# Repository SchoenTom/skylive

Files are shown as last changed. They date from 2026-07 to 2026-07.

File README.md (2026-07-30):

<div align="center">

# SkyLive

### A skydiver exits at 4 000 m. Before the canopy opens, the drop zone is already watching through her eyes.

**Live from 4 km — 14 ms behind reality.**

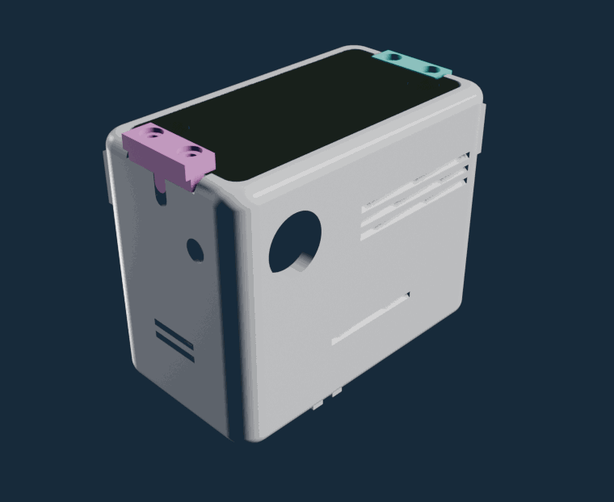
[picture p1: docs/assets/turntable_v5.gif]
The Sender 850 turning slowly: battery door with tab latch, T-clamp antenna anchors on both short sides, roof lid, louvres, GoPro mount.
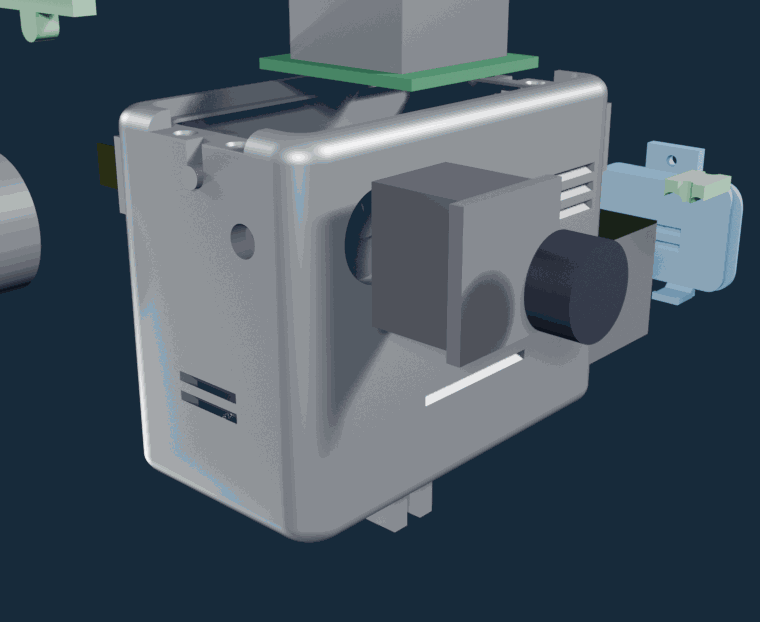
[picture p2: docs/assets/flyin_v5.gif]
Every component — radio, camera, battery, antenna, clamp bars, T-pieces — flying into the open case.
 

<sub>the actual gate-verified CAD — spin it and watch the parts fly home yourself in the [3D Lab](https://schoentom.github.io/skylive/viewer.html)</sub>






**[▶ Play the jump](https://schoentom.github.io/skylive/)** · **[🧊 3D Lab](https://schoentom.github.io/skylive/viewer.html)** · **[🪂 Freefall Simulator](https://schoentom.github.io/skylive/freefall.html)** · **[🚧 Gate Simulator](https://schoentom.github.io/skylive/gates.html)** · **[⚖ vs GoPro](https://schoentom.github.io/skylive/viewer.html)** · **[🎛 Antenna decks](https://schoentom.github.io/skylive/decks/)** · **[Build it — one page](build/QUICKSTART.md)** · **[What the gates caught](build/WHAT_THE_GATES_CAUGHT.md)** · **[The numbers](build/rf/README.md)** · **[Legal (DE)](build/LEGAL_DE.md)**

</div>

---

## What if the whole drop zone could watch — live?

<div align="center">
Left: what the ground sees today — just a dot in the sky. Right: what SkyLive shows — the freefall POV live on a monitor, same moment, ~14 ms.
</div>

Today the ground sees **a dot in the sky**. Spectators, the waiting area, your own team — they follow the jump with the naked eye, and the footage arrives only *after* landing. The moment itself stays invisible.

**SkyLive** puts the jump on the screen **as it happens**. A helmet-mounted transmitter the size of an action cam sends a digital HDZero picture from ~4 km up, down its own 5.8 GHz radio link — no internet, ~14 ms — straight onto the big TV in the waiting area. Not a recording. **The present tense.**

<div align="center">
The signal's journey: camera → 1 W radio → antenna → ~4 km of air → ground antennas → receiver → HDMI → the big TV in the waiting area, in about 14 ms.
</div>

---

## Four parts. Two ways to wire them.

That's the entire transmitter: **a radio, a camera, a battery, and a button.** The simplicity *is* the design — and you pick your wiring path:

- **Soldered (recommended for the flight unit):** every lead cut to its true run length — shorter cables, less weight, nothing to rattle, the most robust joints a jump can ask for.
- **Wago quick-build (great first build):** three 221-412 lever clamps, zero solder, re-openable in seconds — perfect while you're still iterating.

| | part | what it does | the real part |
|---|---|---|---|
| 📡 | **Radio (VTX)** | turns the picture into a 1 W digital signal, ~14 ms | HDZero Freestyle V2 (30 × 29 × 14 mm, runs directly on 3S — no flight controller, no BEC) |
| 👁 | **Camera** | HD skydive POV, 162° | HDZero Nano90 (ships in the VTX kit, powered over its MIPI cable) |
| 🔋 | **Battery** | ~40 min at 1 W (calculated: 850 mAh / ~1.3 A) | Tattu R-Line 3S 850 mAh (XT30) |
| 🔘 | **Switch** | on/off — breaks the battery + line directly | 12 mm latching push-button, panel-mount |

The VTX side plugs in via its stock **JST-GH 6-pin harness** either way. Full step-by-step (with the three hardware-killer rules): **[`build/BUILD_GUIDE.md`](build/BUILD_GUIDE.md)**.

**The shell:** an upright, two-storey GoPro-style case — battery downstairs behind its own tab-locked door, radio + camera upstairs under a screwed roof lid — printed in **PETG/ASA (never PLA)** with a sacrosanct **3 mm wall**, long passive louver vents, and a GoPro mount underneath. Outer dimensions: **71 × 40 × 56 mm** — genuinely action-cam-sized. Both short sides carry an identical **T-clamp strain-relief interface** at the top edge — guide slot, round seat, and a screw-driven nose clamp — so the antenna can anchor left or right; the unused side is closed by the same T-piece. It builds from the parametric script in [`build/cad/`](build/cad/) and passes every geometry gate on each rebuild; this exact file set is what went to the printer.

**Three sizes, one architecture.** Don't take a photo's word for it — **[spin them in the 3D Lab](https://schoentom.github.io/skylive/viewer.html)**, where every dimension tag is a real millimetre from the executed CAD. The **850** (71 × 40 × 56 mm) is the flight unit; the
**mid sender** (72 × 39 × 57 mm) and the **Mini 300** (59.5 × 39.5 × 48 mm) are the same design
wrapped around the smaller Tattu 300 3S HV pack (measured 45 × 17.5 × 15.3 mm) —
same T-clamp antenna anchors (literally the same printed T-piece), same tab door, same camera corner.

---

## One antenna, anchored like a tool — not like an afterthought.

There is **no electronic antenna switch** on the sender — the omni rides outside on its
semi-rigid coax, and the clever part lives where it belongs: on the ground.

The mount is a proper screw clamp, measured off a working reference build's STEP files: the
**Ø 3.1 mm** semi-rigid coax drops from above through a guide slot **all the way down** into a
round Ø 3.2 seat that passes horizontally through the case wall — the seat has clearance, on
purpose. The clamping is the **T-piece's job**: its stem ends in a **convex nose of R 1.55 mm —
exactly the cable's radius** — and two vertical M2 cap screws pull that nose 0.4 mm down onto
the cable, pinching it into the seat. The screws *are* the clamp; a yank on the antenna loads
the printed wall and the bolted nose, never the connector. Outside, the **RHCP omni sits
directly against the wall, its axis horizontal, pointing straight through it**. That 90° turn
is the whole point: an upright omni's donut pattern has its nulls pointing up and down, which
in head-up *and* head-down would aim a null exactly at the receiver. Lying sideways, the donut
fires **down and up and all around** — signal toward the ground in every jump attitude. Both
short sides carry the identical interface, so the anchor moves left or right to suit the helmet
setup — one T-piece design, printed twice, no drilling, no notching.

| honest caveat | status |
|---|---|
| Body shadow, not the antenna, is the limiter in belly/sit poses (−7…−12 dB literature midpoints) | assumption, to be jumped |
| Nose clamp holding force and S11 with the coax clamped | `MEASURE_ME` — fit-print pull test + NanoVNA |
| CAD asserts a 0.4 mm nose-to-cable engagement (1.15 mm³) on every rebuild | calc, not a torque test |

Two earlier antenna integrations — the fully **encapsulated side-capsule omni** and the
**down-firing patch shell** — are preserved as engineering studies with their full RF derivations
in [`build/ENGINEERING/antenna_capsule.md`](build/ENGINEERING/antenna_capsule.md); the external
anchored omni won on serviceability (swap an antenna in seconds, nothing to detune, one part to
reprint).

**The gain lives on the ground.** You're tumbling; the ground isn't. A bigger helmet antenna buys ~2–3 dB; the ground antenna buys 10+ dB. But not by tracking — a mover has a zenith keyhole exactly where the jump happens. The doctrine is **several fixed beams**: one at the zenith, three around the horizon, and the receiver's 4-way diversity fuses the branches. The beams themselves are **self-printed axial-mode helix antennas** (5.8 GHz, RHCP, 7 turns, C/λ 1.00, 10.5° pitch, copper-tape cup reflector — the higher-gain cone *loses* in the minimax over real geometry despite +4 dB peak; HPBW ~37°). Gain, honestly: estimators span **10.7–13.9 dBic — measurement decides.** Each helix sits on a ball head so elevation is set in the field, the receiver's stock 2 dBi stubs come off (HDZero fuses by data integrity — one bad branch degrades the whole picture), and a Wi-Fi scan of the drop zone happens before anything transmits (5.8 GHz video channels overlap Wi-Fi). The store-bought patch-plus-omnis set remains as the interim/comparison station.

---

## The numbers — calculated, labelled, and published even when they got worse

<div align="center">
Link budget at 4 km: +30 dBm transmit, −119.8 dB free-space loss, honest RX gain, −90 dBm threshold — head-down closes with margin, belly rides the threshold; a model, not a measurement.
</div>

| | value | status |
|---|---|---|
| 📡 Transmit power | +30 dBm (1 W) — 25 mW SRD for all tests, PMSE assignment for the event | planned path |
| 📡 Free-space loss @ 4 km | 119.8 dB (5.8 GHz, Friis) | derived |
| 📡 Link margin @ 4 km | **head-down ≈ +9 dB** · back ≈ +3 dB · **belly rides the threshold** (−0.2 dB) · sit ≈ −2 dB — margins improve 2–3 dB per km of descent | **calculated, not measured** |
| 🧍 Body shadow | −7…−12 dB with the side-mount offset (literature midpoints) — the single biggest uncertainty | assumption, to be jumped |
| 🌡 Heat at 1 W | **~13 W of waste heat.** On the ground, in still air, no passive case can hold that — so the doctrine is 25 mW on the ground, **1 W only at door-open**; in freefall the 200 km/h wind is the heatsink (4–8× surplus) | calculated |
| ⏱ Latency | ~14 ms | manufacturer figure |

The full model — pattern math, pose-by-pose margin tables, every assumption and its direction of error — is in [`build/rf/`](build/rf/), including an **interactive link-budget explorer** you can open in any browser. The thermal, structural and print derivations live in [`build/ENGINEERING/`](build/ENGINEERING/).

> **No overclaiming.** A CAD boolean check is not a test. Nothing in this repo carries a *measured* badge yet — and when the 2026 recalculations made numbers worse, the worse numbers were published.

---

## Build one yourself

Everything a re-builder needs is under [`build/`](build/):

- 📋 **[`BUILD_GUIDE.md`](build/BUILD_GUIDE.md)** — both wiring paths (soldered flight build, Wago quick-build), the wiring map, the three hardware-killer rules, and the power/thermal operating doctrine.
- 🛒 **[`BOM.md`](build/BOM.md)** — every part with real EU prices (as of 2026-07).
- 📐 **[`MEASURE.md`](build/MEASURE.md)** — the dimensions you must caliper yourself (nothing in this project is guessed).
- ✅ **[`VERIFICATION.md`](build/VERIFICATION.md)** — how a CAD model is turned into a *trustworthy* printable part: a seven-layer defense-in-depth, the honest limits of gates vs. physical tests, and the release checklist.
- ⚖️ **[`LEGAL_DE.md`](build/LEGAL_DE.md)** — the German regulatory situation, honestly: what is legal today (25 mW SRD), what the event path is (PMSE), and why 1 W under an amateur licence is locked pending clarification.
- 🧊 **[`cad/`](build/cad/)** — the parametric build123d scripts (`spec.py` is the single source of truth for every dimension).

<div align="center">
Latency: ~14 ms — before you blink. The old way is footage seen only after landing.
</div>

---

## Status

**Print released** (2026-07). The concept, the electronics, the RF doctrine and the engineering derivations are done and published here; the case design is frozen, and the first fit-prints are back from the printer: the printed GoPro fork clicks into a real GoPro mount and the parts fit as drawn (builder fit test, 2026-07-15).

- ✅ Sender electronics bought and specified — four parts, two wiring paths (soldered flight build, Wago quick-build).
- ✅ RF doctrine derived and published (donut orientation, multi-beam ground station, legacy capsule study) — *calculated*.
- ✅ Thermal, structural and print-factor derivations published — *calculated*.
- ✅ Final case CAD (**71 × 40 × 56 mm**) builds watertight and passes every geometry gate — roof lid on 2 diagonal M3 corner inserts (was 3 — round-2 port), tab-locked battery door, twin T-slot antenna anchors, 3 mm wall. **Print files released — and the first fit-prints are back: the GoPro interface locks into a real mount, the parts fit.** *Fit-verified by print (2026-07-15); strength and RF stay open below — a fit is a geometry result, not a pull test.*
- ✅ **Mid sender** (72 × 39 × 57 mm) and **Mini 300** (59.5 × 39.5 × 48 mm, Tattu 300 3S HV): full architecture ports of the final build — same T-slot anchors (the T-pieces are literally the same printed part), same tab door; the Mini has no power switch (the electronics storey has no room for one; power = plug the battery). [`build/cad/mid_sender.py`](build/cad/mid_sender.py) · [`build/cad/mini_300.py`](build/cad/mini_300.py), *geometry-verified, not yet printed.*
- ✅ **Engineer feedback round 2 (2026-07-25), mid sender:** printed prototypes went through a professional mechanical review — everything that broke, broke at a layer seam while removing support. Fixes, each proven by a point-cloud diff against its target zone ([`build/cad/mesh_diff.py`](build/cad/mesh_diff.py)): mid back to **71 mm** (a 2 mm squeeze had eaten the power-switch bay — the switch check is a hard, whole-body gate now), camera flange rooted on the mid-storey shelf, XT30 strain relief rebuilt as a wall-to-wall clamp bridge with a solid latch bar, door teeth straight with 45° fan roots into the plate, omni side-holders removed, roof lid down to 2 diagonal M3. **One-material doctrine:** colour metadata in the STEP exports had been flipping lab printers into multi-material mode (seven aborted prints) — all exports are colour-free now; slice the STLs only. *Geometry-verified (mesh diffs, hard gates, 6/6 printability); the round-2 fit-print is still open.* Sub-mm audit: [`build/cad/SUBMM_INVENTUR_2026-07-25.md`](build/cad/SUBMM_INVENTUR_2026-07-25.md).
- ✅ **Unified port (2026-07-26): all three senders now follow the same principles.** Camera foot, wall-to-wall XT30 clamp bridge + flat latch v3, straight door teeth with a full-width root bar, omni side-holders removed — ported to the 850 and Mini 300 with each model's own gates re-proving the result (the Mini rejected the diagonal-lid port outright: its corner boss would sit inside the VTX envelope, 320 mm³ — its two edge screws stay). Lid rim audited on all three (≥1.4 mm standing lip; the mid's Y-lap dropped to 1.25 to get there), and every door louver now has to prove 19/19 free 45-degree air paths at export — perviousness is invisible in renders, so it became a gate.
- 🔜 Then: thermal measurement (multimeter protocol is written) → antenna S11 with the coax clamped → clamp pull test → 25 mW range test → test jump.

### Modelled → gated → printed — the provenance trail

Everything physical in this project traces end to end; nothing here is a mockup:

- **Modelled.** Three senders — 850, mid, Mini 300 — each generated by one executed build123d
  script ([`v3_min.py`](build/cad/v3_min.py) · [`mid_sender.py`](build/cad/mid_sender.py) ·
  [`mini_300.py`](build/cad/mini_300.py)), six printed parts per size: the one-piece two-storey
  **body**, the tab-locked **battery door** (M2 brass insert), the **roof lid** (3× M3 corner
  inserts), **2× XT30 clamp bar** and **2× strain-relief T-piece** (proud + flush). The GoPro
  two-prong fork is printed into the floor of the body — teeth 3.0, gap 3.3, drawn against
  caliper-measured hardware. All 18 release STLs live in [`build/stl/`](build/stl/).
- **Gated.** Every STL passed the release chain before it was allowed to exist: watertight
  boolean, the nominal-envelope interior gates (the same arithmetic the
  [Gate Simulator](https://schoentom.github.io/skylive/gates.html) replays), and
  [printability gate v2](build/cad/printability_gate.py) — thin-wall plateau = FAIL, cosmetic
  cusp = WARN. What the gates caught on the way is documented in
  [`WHAT_THE_GATES_CAUGHT.md`](build/WHAT_THE_GATES_CAUGHT.md); the layer-by-layer method in
  [`VERIFICATION.md`](build/VERIFICATION.md).
- **Printed.** The first fit-prints are back (PETG, per [`PRINT_DE.md`](build/PRINT_DE.md)):
  **the printed GoPro fork clicks into a real GoPro mount, and the printed parts fit as
  drawn** — builder fit test, 2026-07-15. That upgrades the GoPro row in the ledger below from
  *printing* to *fit-verified*. Still open and honestly labelled: thermal, S11 and the pull
  test — a part that fits is a geometry result, not a strength or RF result.

⭐ **Star the repo** — releases will carry the first real measurements and, eventually, the first freefall footage from the system itself. Building one, or flying camera and have opinions? Open an [issue](https://github.com/SchoenTom/skylive/issues).

---

## The jump, as a number line

```
4000 m ─┤ ██ EXIT      link margin: head-down +9 dB · belly −0.2 dB   [CALC]
3000 m ─┤ ██ freefall  ~200 km/h — the airstream IS the heatsink      [CALC]
1500 m ─┤ ██ canopy    margins improve 2–3 dB per km of descent       [CALC]
 300 m ─┤ ██ pattern   fixed ground beams — the receiver fuses 4 branches
   0 m ─┴─▓▓─ beer     footage was live the whole way down            [PLAN]
```

<sub>margins = the conservative single-beam floor from [`build/rf`](build/rf); the BoxPro's
four fused helix branches ride 10–15 dB higher — [fly it yourself in the simulator](https://schoentom.github.io/skylive/freefall.html).</sub>

## Truth ledger — what is measured, what is math

The whole repo runs on a two-word doctrine: **a CAD boolean is not a test.** Current state of
every load-bearing number:

| number | value | status |
|---|---|---|
| case dimensions, all three senders | 71×40×56 · 72×39×57 · 59.5×39.5×48 | 🟢 executed CAD, gate-checked |
| battery | 58×30×22 (850) · 45×17.5×15.3 nominal — the real wrapped pack binds at 18.25 light width, guides opened to 18.75/16.55 (mid + Mini | 🟢 measured with calipers |
| brass inserts | M3 Ø5×6 · M2 Ø3.2×3 | 🟢 measured |
| XT30 wire, coax jacket | Ø2.8 · Ø3.1 | 🟢 measured |
| GoPro teeth 3.0 / gap 3.3 | printed — clicks into a real GoPro mount, fits as drawn | 🟢 fit-verified by print (2026-07-15) |
| antenna clamp holding force | screw-driven nose, 0.4 mm engagement (calc) | 🔴 MEASURE_ME — pull test pending |
| antenna S11, insert strength, snap cycles | — | 🔴 MEASURE_ME |
| link budget @ 4 km, thermal model | full derivations in build/rf | 🟡 CALC — to be jumped |

🟢 measured · 🟡 calculated/derived and labelled · 🔴 open, honestly. When the 2026 recalculations
made numbers worse, the worse numbers were published — that policy stands.

## Honest note

A solo-built, prototype-stage project shared in full. Calculated values are marked as such and separated from what still has to be measured. Transmit power is regulated: the plan of record is licence-free **25 mW SRD** for all development tests and a **PMSE short-term frequency assignment** for event operation — see [`DISCLAIMER.md`](DISCLAIMER.md) and [`build/LEGAL_DE.md`](build/LEGAL_DE.md).

<sub>License: <a href="LICENSE">CC-BY-4.0</a> · CAD: build123d (Python) · Made by <a href="https://github.com/SchoenTom">@SchoenTom</a></sub>

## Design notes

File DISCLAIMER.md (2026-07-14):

# ⚠️ Disclaimer — RF, safety, status

**SkyLive** · Copyright (c) 2026 Tom Schoen ([@SchoenTom](https://github.com/SchoenTom)) · Licensed [CC BY 4.0](LICENSE)

## Radio / regulatory

Radio transmit power is regulated. The plan of record for this project is **licence-free SRD at 25 mW EIRP** for all development and testing and a **PMSE short-term frequency assignment** (BNetzA, Germany) for event operation. Operating at 1 W under an amateur-radio licence is a legal grey zone in Germany (§5 AFuG / §16 AFuV, plus a hard bandwidth cap) — it is *not* what this project relies on; the full reasoning is in [`build/LEGAL_DE.md`](build/LEGAL_DE.md). **Anyone reproducing this work is responsible for their own regulatory compliance in their own jurisdiction.**

## Safety

This device is designed to be worn on a skydiver's helmet next to life-critical equipment. The documentation includes the safety concept (snag-free shell, screw-clamped captive antenna, tab-locked battery door, strain relief, thermal operating doctrine, SAR assessment and AAD manufacturer sign-off as hard gates before any jump) — **none of it is validated yet**. Do not jump any build of this hardware before the documented ground gates pass, a written AAD manufacturer statement exists, and the drop zone / safety officer has approved it.

## Status

Prototype-stage engineering, shared in full. Calculated values are marked as calculated; nothing carries a "measured" badge yet. The material is provided **"as is", without warranty of any kind**. This is not a validated, certified, or sellable product.

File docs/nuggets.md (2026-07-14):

# SkyLive — five numbers that carry the design

*Five engineering "nuggets" — one number each, a few sentences each. The kind of small, exact
figure that a whole design quietly hangs on. Sourced where sourced, **[CALC]** where modelled,
honest either way. Card texts for the show layer; the derivations live in [`../build/`](../build/).
These five render as number cards in the Pages site (docs/index.html).*

---

### R 1.55
**The nose that matches the cable exactly.**
The antenna cable drops all the way down into a round seat with clearance — insertion never fights
the print. Then the T-piece's stem lands on it: a convex nose of radius 1.55 mm, precisely the
cable's own radius, so it cradles instead of cutting. Two vertical M2 screws pull that nose 0.4 mm
onto the cable — the screws are the clamp, measured 1:1 off a working reference build. A yank on
the antenna loads the printed wall and the bolted nose, never the connector.

---

### −0.2 mm
**The squeeze standard (where squeezing is right).**
The battery-lead saddles are under-sized by a tiny, deliberate amount: 0.2 mm less than the wire
they hold. It's the line between gripping and crushing. The antenna clamp deliberately does NOT use
it — coax hates being squeezed by tolerances (it detunes), so there the seat has clearance and two
screws deliver a controlled, serviceable clamping force instead. Same goal, two honest mechanisms.

---

### 90°
**The turn that dodges the null.**
The omni doesn't stand upright like on an FPV quad — its coax runs horizontally through the case
wall and the bell sits directly against it, axis pointing straight through the wall. An upright
omni's donut pattern has nulls straight up and down: in head-up or head-down freefall that aims a
blind spot exactly at the receiver. Laid sideways, the donut fires down, up and all around — signal
toward the ground in every jump attitude. And the strain relief becomes trivially simple: the cable
never turns, so the T-clamp just drops onto it and screws shut.

---

### 14 ms
**Glass-to-glass latency.**
From the lens in freefall to the picture on the ground TV is about 14 milliseconds — faster than a
blink, faster than you can perceive as delay (manufacturer figure). It's not the internet and it's
not a stream; it's a private digital radio link with nothing in the middle to buffer. The jump you
watch on the screen *is* the jump happening in the sky, in the present tense.

---

### 4 parts
**No flight controller. No BEC. One printed body.**
The entire transmitter is four things — a radio, a camera, a battery, and an antenna — inside one
printed body. Every FPV builder expects a flight controller, a voltage regulator, a rat's nest of
wiring; there is none of it here. The few joints that remain are soldered once, properly, for
flight — every joint earns its place. The restraint *is* the engineering: fewer parts, fewer
failure points.

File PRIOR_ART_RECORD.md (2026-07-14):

# SkyLive — Prior-Art / Authorship Record ("Sicherheit B")

**Purpose:** dated internal record of authorship of the SkyLive concept — an
open, helmet-mounted 5.8 GHz live-video *sender* + open ground-station system for
broadcasting a skydiver's own point of view to the drop zone in real time — kept
as a backup in case the idea is copied.

**Recorded:** 2026-07-08
**Author / owner:** GitHub `SchoenTom` (this is the account of record for SkyLive).

---

## ⚠️ The primary proof is NOT this file

A local file's timestamp can be altered, so it is weak on its own. The
authoritative, hard-to-repudiate evidence of first public disclosure is:

- **"Sicherheit A" — the public repo `skylive` on GitHub** (`SchoenTom/skylive`),
  with **server-side git commit timestamps** and the **CC-BY-4.0 license**
  (which legally requires attribution to the author on any reuse). That is
  timestamped public prior art. This file is a supplementary backup only.

To harden the anchor further (optional, recommended):
- Commit *this* record into the public repo so it, too, gets a server timestamp.
- Cut a dated, tagged release of the concept docs.
- Add an external timestamp (e.g. OpenTimestamps) to a hash of the key files.

---

## Context of this record

On 2026-07-08 the author applied to Anthropic's open-source / Claude Max program,
presenting SkyLive as the flagship project. This file preserves the submitted
description of the concept as of that date.

## The concept, as disclosed

An **open-source, reproducible** system — buildable by anyone — that live-streams
a skydiver's own point of view to the drop zone as the jump happens
(~14 ms latency, ~4 km range, 5.8 GHz HDZero). Novelty vs. prior state: this
capability existed only in **closed, commercial** broadcast rigs; SkyLive
publishes the **whole chain — helmet sender to open Linux ground station** —
under CC-BY-4.0 so anyone can rebuild it. Deliberate full disclosure (the
patentable ideas were released rather than locked up).

*(2026-07-14 note: the ground-station concept has since evolved into a multi-beam
station with self-printed helix antennas.)*

## Submitted application answers (verbatim, as of 2026-07-08)

**Q1 — reach & impact / gap in the ecosystem:**
> My mission is to make everything I build open and freely reproducible, so
> anyone can use it — not only hardware, but quantitative-finance research that is
> normally locked behind institutions and paywalls. I publish my results and tools
> openly so students, independent researchers, and everyday people can benefit from
> methods usually reserved for a few. My flagship project, SkyLive, carries that
> same spirit into a field that has no open answer yet: it takes a capability that
> today exists only in closed, commercial form and turns it into a fully open
> design anyone can rebuild.

**Q2:**
> The impact I aim for is access: taking things that are normally closed,
> expensive, or locked behind institutions — from finance methods to hardware —
> and making them open, reproducible, and free for anyone to use, verify, and
> adapt. My work is meant to belong to the people who use it rather than to a
> vendor's customers. SkyLive is one example of that, opening a capability a whole
> community could never afford before.

**Q3:**
> Everything I build is developed in the open, across finance and hardware, and I
> publish the results and tools so others can use and verify them — not just read
> about them. It's an early but growing body of work, reproducible from day one,
> aimed at steadily widening who gets access. SkyLive is the flagship carrying
> that forward.

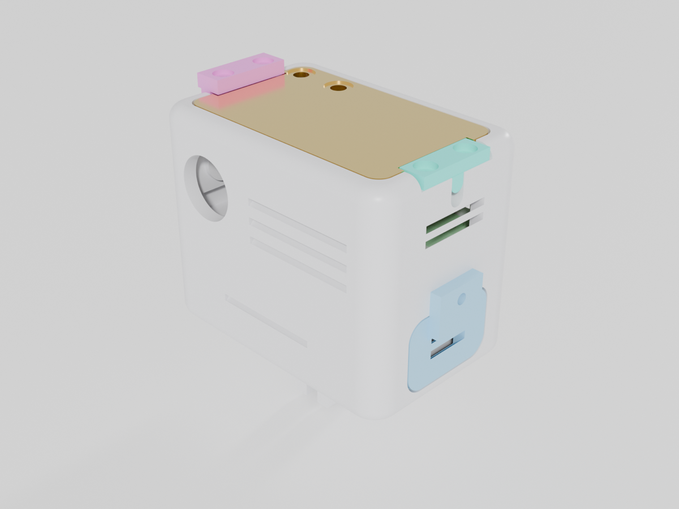
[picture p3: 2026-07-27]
docs/poster_mini_v1.png

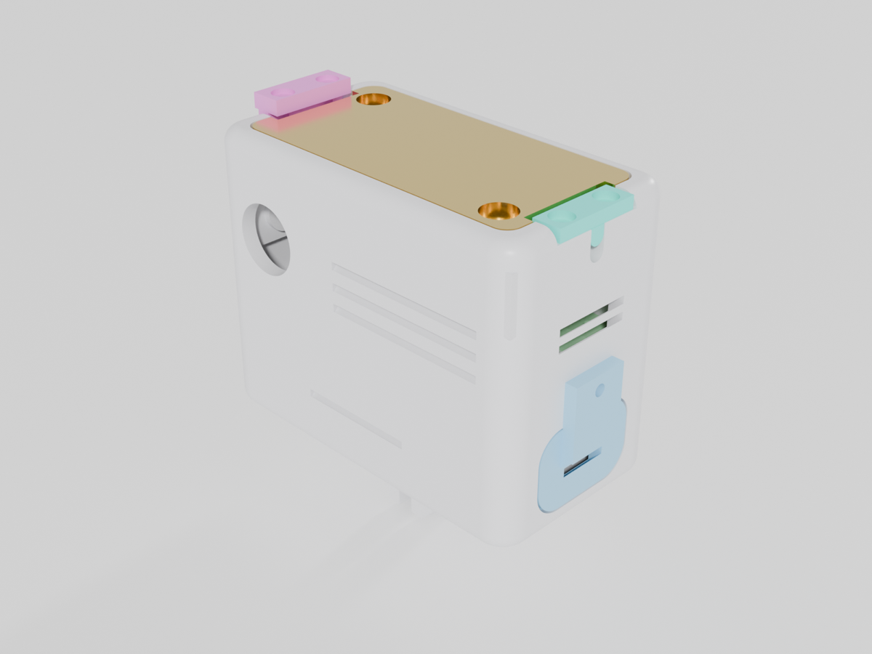
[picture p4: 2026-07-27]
docs/poster_mid_v1.png

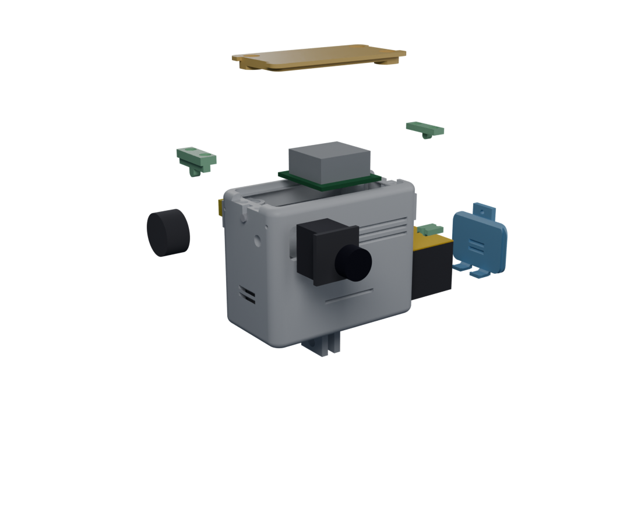
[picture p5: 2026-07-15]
docs/poster_exploded_v4.png

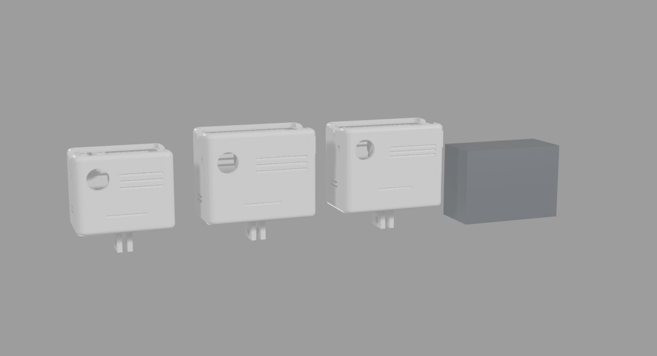
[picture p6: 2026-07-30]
docs/poster_cmp_v2.png

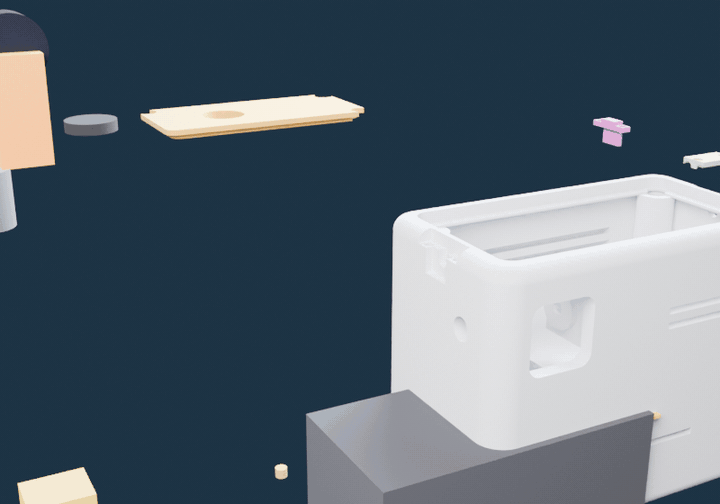
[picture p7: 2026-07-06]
docs/assets/flyin.gif

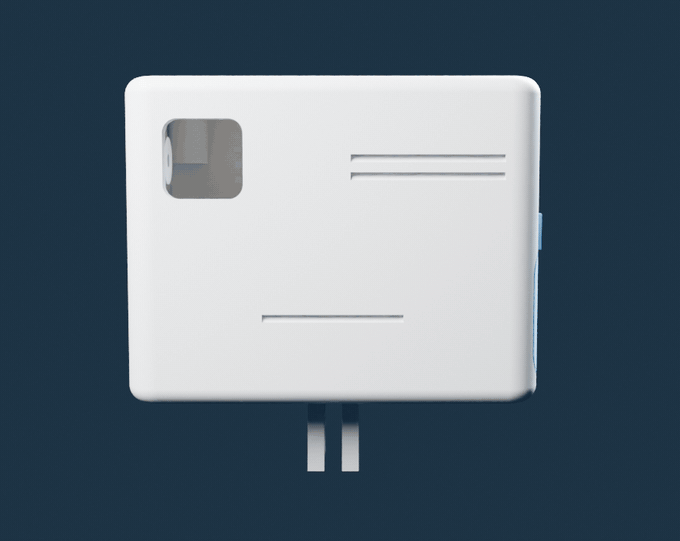
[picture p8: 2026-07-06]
docs/assets/turntable.gif

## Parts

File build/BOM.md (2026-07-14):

# SkyLive — Bill of Materials

*Prices as of 2026-07, EU/DE vendors, from the project's real order log (German original:
`BESTELLLISTE_SENDER_FINAL`). Stock and prices rotate daily in FPV shops — verify on the day
you click. Items marked “—” were already owned or not in the logged order.*

## 1 · Sender — the four functional parts

| # | part | exact product | ≈ € | note |
|---|---|---|---|---|
| ① | VTX + camera + MIPI | **HDZero Freestyle V2 VTX Kit** (incl. Nano90 camera, MIPI cable, stock antenna) | 179.95 | cheaper than buying VTX (118.95) + camera separately |
| ② | Battery | **Tattu R-Line 3S 850 mAh, XT30** (850 flight unit) · **Tattu 3S 300 mAh HV** (mid + Mini 300; measured 45 × 17.5 × 15.3 mm) | 14.99 | ×3 bought for bench rotation; cold-rated packs only for the real jump |
| ③ | Switch | **12 mm latching push-button, pre-wired** (2 A / 12–250 V) | ~5 | Amazon-class part; voltage/current-safe for 3S @ ~1.3 A |
| ④ | Power joins | solder + heat-shrink (flight build) **or 3× Wago 221-412** lever clamps (quick-build) | ~3 | the soldered build is the recommended flight configuration; the Wagos are the re-openable first-assembly path |

## 2 · Antenna path (one SMA joint inside — U.FL touched exactly once)

| part | role | ≈ € | note |
|---|---|---|---|
| **TBS SMA pigtail, U.FL → SMA flange, 60 mm** | the fixed inner joint that protects the VTX U.FL (~30 cycles) | 5.99 | ×4 bought (spares — treat as consumable) |
| **Lumenier AXII 2, RHCP, SMA** | **the donut omni** — captive against the short case wall, axis horizontal through it, coax held by the screw-driven T-clamp | — | 73 × 17.5 mm, 7.8 g, 2.2 dBic, 5.3–6.2 GHz (manufacturer page) |
| **TBS 5G8 patch, RHCP** | *legacy study only* — the down-patch variant survives as an engineering study, not a fitted part | 11.90–14.90 | ⚠ exists in SMA and RP-SMA variants — the study's patch is **RP-SMA**; match your pigtail, SMA ≠ RP-SMA |
| SMA↔RP-SMA adapter kit | catch-all for any connector mix | ~6 | Amazon kit |

### Antenna test kit (bought deliberately — the shoot-out is part of the project's honesty)

| part | ≈ € | why |
|---|---|---|
| TrueRC OCP 5.8 omni, RHCP, SMA (×2) | 15.99 ea. | omni comparison candidate |
| Foxeer Micro Lollipop, RHCP, U.FL | 18.90 | budget omni comparison |
| TrueRC Matchstick Carbon Long, RHCP, U.FL | 29.90 | premium omni comparison |
| Linear λ/2 dipole, U.FL | 1.85 | **only** to demonstrate the −3 dB polarization penalty vs a true RHCP omni — not a fitted part |

## 3 · Case & assembly consumables

| part | ≈ € | note |
|---|---|---|
| PETG (prototypes) / **ASA (final)** filament | ~25/kg | never PLA — it softens too low; case files `TBD-CAD-M6` |
| Silicone thermal pad, 1.5 mm, ≥ 3 W/mK | ~8 | VTX face → wall, mandatory |
| M3 heat-set inserts (Ruthex RX-M3x5.7 class) + M3 screws | ~10 | roof-lid corner posts |
| M2 DIN 912 cap screws: 4× M2×8 (antenna T-pieces) + 1× M2×6 (door tab) + 4× M2×8 (XT30 latches) + 2× M2 (camera) | ~4 | all cap-head (project standard) |
| M2 brass heat-set insert, Ø3.2 × 3.0 (measured) | ~1 | door-tab thread — the most-cycled screw (every battery swap) gets brass, not self-tapped PETG; T-pieces/latches stay on Ø1.7 printed cores (low-cycle) |
| TPU filament | ~15 | only needed for the *legacy capsule study* (tip pad + root ring) — the anchored-omni build uses none |
| Heat-shrink, RTV/hot glue, zip ties | ~5 | Wago securing + strain relief |
| Soft foam padding, ~2 mm (EVA/PE) | ~3 | **mandatory** battery preload — the pack must never fly free in the bay (a loose 80 g pack hits ~590 N on a hard stop; the foam cuts that to ~250 N) |
| 50 Ω SMA dummy load | ~8 | safe bench power-up without an antenna |

## 4 · Ground station — several fixed beams (self-printed helix antennas)

The doctrine changed: no tracker, no combiner — **multiple fixed beams (zenith + horizon), the
receiver fuses the branches.** The beams are self-printed 5.8 GHz axial-mode helices (RHCP,
7 turns, C/λ 1.00, pitch 10.5°, cup reflector with copper tape inside, HPBW ~37°). Gain,
honestly: **estimators span 10.7–13.9 dBic — measurement decides.** Unscrew the BoxPro's stock
2 dBi stubs (one bad branch degrades the fused picture) and **Wi-Fi-scan the DZ before operating**.

| part | role | ≈ € |
|---|---|---|
| **HDZero BoxPro** | 4-way diversity RX, Mini-HDMI out to the TV | ~360–420 |
| **Helix antenna, self-printed** (per branch): ~45 cm of 1.5 mm bare copper wire, 0.3 mm brass/copper sheet (ground plane), copper tape, SMA bulkhead, 3× M3×14, 1/4" nut, ASA prints (former + reflector + ball-head base + feed gauge) | one fixed beam; **ball-head mount** so elevation is set in the field | ~10–15 |
| Gas discharge tube or λ/4 shorted stub at the VRX input | static from wind/rain on the wire kills the frontend otherwise | ~3 |
| HDMI cable + public-viewing TV/monitor | the whole point | — |

*Interim/comparison station (store-bought, superseded as doctrine): TrueRC X²-AIR MK II patch
(nominal 13 dBic, budget ~10, ~€60) · Lumenier Double AXII 2 LR (~4.7 dBic, ~€30) · TrueRC
Matchstick Carbon Long (~1.9 dBic, €29.90). Kept for the measured A/B against the helices.*

## 5 · Tools & measurement (staged — bench first)

| item | ≈ € | stage |
|---|---|---|
| **Multimeter** | ~25 | now — polarity check is a hard gate before first power |
| Balance charger 3S (+ XT60→XT30 adapter) | ~40 | now |
| K-type probe thermometer or IR thermometer | 10–20 | thermal A/B test (see [`MEASURE.md`](MEASURE.md)) |
| VNA covering 5.8 GHz (LiteVNA class — a NanoVNA-H does **not** reach the band) | ~120 | before trusting any antenna RF claim (sender clamp S11, helix SWR) |

## 6 · Alternatives (with dims)

*Every part below is a real, buyable component with a verifiable published dimension (or an
honest "dims unpublished" where the maker only ships CAD). "Fits as-is" means it drops into the
current case concept; "fits with note X" means it works but changes something you must account
for. Wall thickness is never traded for volume — see the wall-thickness doctrine.*

### 6.1 · VTX alternatives (core: Freestyle V2 = 29.2 × 30 × 14.1 mm, U.FL, 20×20 M2)

| part | L×W×H | interface | fit |
|---|---|---|---|
| **HDZero Freestyle V1** (30×30) — the backup unit on hand | 40 × 42 × 10 mm, 28 g | U.FL, **30×30 M3** mount | **fits with rework**: larger footprint (40×42 vs 29.2×30) but thinner (10 vs 14.1) → needs a **wider, shallower VTX bay** and a 30×30 M3 boss pattern instead of 20×20 M2. Same 1 W class, same U.FL-once rule. |
| **HDZero Race V3** | 28 × 32 × 5 mm, 5.5 g | U.FL, 20×20 M2 mount | **fits with note**: smaller and far thinner than the V2 (frees bay depth), 20×20 M2 boss pattern matches. **But max 200 mW, not 1 W** (4–12 V input, no 6S) → this is a link-budget downgrade, not a like-for-like swap — only for a short-range/low-power build. |

### 6.2 · Camera alternatives (core: Nano90 = 14 × 18.5 × 19 mm, MIPI 20-pin)

| part | L×W×H | interface | fit |
|---|---|---|---|
| **HDZero Nano V3** | 14 × 16 × 14 mm, 2.2 g | MIPI 20-pin | **fits as-is** — nano-class body, essentially interchangeable with the Nano90 in the same clamp; Starlight low-light sensor is a bonus. |
| **HDZero Micro V2** | 19 × 19 × 21 mm, 8.5 g | MIPI, 19×19 mount | **requires camera-bay rework** — the 19 mm square micro body does **not** fit the ~15 mm nano clamp; you would re-cut the camera bay for a 19×19 front mount. |

### 6.3 · Battery alternatives — **rule: ≤ 60 × 30 × 23 mm fits the bay; a shorter pack = more XT30 room**

Core (850 flight unit): Tattu R-Line 3S 850 = 60 × 30 × 23 mm datasheet (measured **58 × 30 × 22 —
the measured pack governs the bay**), XT30. All 3S / XT30. Long-type "pencil" packs
(≈ 72–74 mm) **exceed the 60 mm bay length** — do not force them.
The **mid and Mini 300** bays are sized around the **Tattu 3S 300 mAh HV** (measured
45 × 17.5 × 15.3) — the 850-class packs do not fit those two.

| part | L×W×H | interface | fit |
|---|---|---|---|
| **Tattu R-Line 3S 450** (compact) | 45 × 24 × 21 mm | XT30 + JST-XH | **fits as-is** — 15 mm shorter than the 850 → generous XT30 slack; shortest airtime. |
| **GNB/Gaoneng 3S 550** (standard) | 58 × 31 × 17 mm | XT30 + JST-XH | **fits with note**: length/height fine, width **31 mm is ~1 mm over the 30 mm bay** → snug; rely on the mandatory foam preload, don't over-compress. |
| **CNHL Pizza 3S 600** | 74 × 12 × 24 mm | XT30 | **does not fit as-is** — 74 mm length exceeds the 60 mm bay by 14 mm; listed only to illustrate the rule (long-type packs are out). |

### 6.4 · Antenna alternatives (RHCP omni; core: Lumenier AXII 2 = Ø17.5 × 73 mm, SMA)

The captive-antenna coax clamp leaves a **~2.9 mm gap** — that grips the thin coax *cable*, not a
molded antenna head. Any SMA omni below swaps at the **SMA joint** exactly like the AXII 2; only
the coax that runs to the clamp matters for the gap.

| part | Ø × L | interface | fit |
|---|---|---|---|
| **Foxeer Lollipop 4 Plus** | head Ø15 × ~60 mm, 7.3 g, 2.6 dBic | SMA (RHCP) | **fits with note**: swaps at SMA like the AXII 2; the **Ø15 molded head will not pass the 2.9 mm coax clamp** — clamp the thin coax/SMA base, never the head. Shorter than the AXII 2. |
| **TrueRC Singularity 5.8 SMA** | head Ø11.8 × 8.2 mm, overall ~120 mm (length varies), 1.9 dBic stubby option | SMA (RHCP) | **fits as-is** — smallest CP head on the market; its thin flexible coax (~Ø1.1) actually suits the 2.9 mm clamp. Lower gain than the AXII 2 — a size/gain trade. |

### 6.5 · Switch alternatives (core: 12 mm latching, 2 A)

| part | dims | interface | fit |
|---|---|---|---|
| **12 mm anti-vandal latching** (Langir / APIELE / RJS class) | Ø12 mm thread, **12.2 mm panel cutout**, body ~28.7 mm long (excl. terminals), panel 1–11 mm | pre-wired or solder-tag | **fits as-is** — identical 12 mm dimensional family, same panel cutout. ⚠ **Verify current rating ≥ 2 A**: many 12 mm latching switches are rated only 1–2 A, and momentary-only variants exist — the + line carries ~1.3 A continuous, so a sub-2 A or momentary part is unsafe/wrong. |

### 6.6 · Heat-set insert alternatives (core: our bosses = Ø4.6 × 8 mm holes for a Ø5 × 6 insert)

| part | OD × length | recommended hole | fit |
|---|---|---|---|
| **ruthex RX-M3×5.7** | length 5.7 mm; OD not published on the product page (CAD download only) — M3×5.7 class is smaller than our Ø5 | Ø4.0 mm (per maker) | **fits with rework** — drill the bosses to the **maker's hole (Ø4.0)**, not our Ø4.6; an oversized hole lets the insert spin. |
| **CNC Kitchen M3×5.7** | length 5.7 mm; OD per maker CAD (M3-standard) | Ø4.0–4.2 mm (per maker) | **fits with rework** — same story: match the boss hole to CNC Kitchen's 4.0–4.2 mm spec, not our Ø4.6. Blind hole ≈ 1 mm deeper than the insert. |

**Rule:** a different insert = a different pilot hole. Always drill to the *insert maker's* spec,
not to our Ø4.6 (which is sized for the Ø5 × 6 insert).

### 6.7 · Wago alternative (core: 221-412, 2-conductor lever nut)

| part | L×W×H | conductors | fit |
|---|---|---|---|
| **Wago 221-2411** (inline splice) | 35.5 × 8.1 × 8.9 mm, 0.2–4 mm² | 2, **feed-through** (in one end, out the other) | **no direct 1:1 substitute** — different topology. The 221-2411 is a *straight inline* joiner (slim, wires enter opposite ends), handy where the + line runs end-to-end; the 221-412 is the general junction block. Keep the 221-412 for the main +/− joins; use the 2411 only for a clean inline splice. |

### Sources (§6)

- [HDZero Freestyle V1 VTX — docs](https://docs.hd-zero.com/freestyle-v1) · [Freestyle 30×30 listing (40×42×10, 28 g, 30×30 M3)](https://www.racedayquads.com/products/hdzero-freestyle-30x30-25-1000mw-digital-hd-vtx-u-fl)
- [HDZero Race V3 VTX — docs (28×32×5, 5.5 g, 25–200 mW, 20×20)](https://docs.hd-zero.com/race-v3) · [Race V3 review — Oscar Liang](https://oscarliang.com/hdzero-race-v3-vtx/)
- [HDZero Nano V3 camera — docs (14×16×14, 2.2 g)](https://docs.hd-zero.com/camera-nano-v3)
- [HDZero Micro V2 camera (19×19×21, 8.5 g, 19×19 mount)](https://www.getfpv.com/runcam-hdzero-micro-camera-v2.html)
- [Tattu R-Line 3S 450 (compact) — genstattu](https://genstattu.com/tattu-450mah-11-1v-75c-3s1p-lipo-battery-pack-with-xt30-plug.html) · [GNB 3S 550 standard (58×31×17)](https://pyrodrone.com/products/gaoneng-gnb-111v-550mah-80-160c-3s-lipo-battery-jst-xt30) · [CNHL Pizza 3S 600 (74×12×24)](https://chinahobbyline.com/products/cnhl-pizza-series-600mah-11-1v-3s-120c-lipo-battery-with-xt30)
- [Foxeer Lollipop 4 Plus (2.6 dBic, SMA)](https://www.foxeer.com/foxeer-lollipop-4-plus-high-quality-5-8g-2-6dbi-fpv-omni-lds-antenna-g-374) · [TrueRC Singularity 5.8 SMA (head Ø11.8×8.2)](https://truerc.com/71964-singularity-58-sma)
- [12 mm anti-vandal latching switch — dimensional family](https://www.langir.com/l12-anti-vandal-switch/) · [12 mm switch panel/thread data — APIELE](https://www.apiele.com/collections/12mm-latching)
- [ruthex RX-M3×5.7 insert (length 5.7 mm, CAD only)](https://www.ruthex.de/en/products/ruthex-gewindeeinsatz-m3-100-stuck-rx-m3x5-7-messing-gewindebuchsen) · [CNC Kitchen M3×5.7 + hole guide](https://www.cnckitchen.com/blog/tipps-amp-tricks-fr-gewindeeinstze-im-3d-druck-3awey)
- [Wago 221-2411 inline splice (35.5×8.1×8.9)](https://www.wago.com/global/installation-terminal-blocks-and-connectors/inline-splicing-connector-with-levers/p/221-2411)

## Order-log reality notes (kept, because they will bite you too)

- The **VTX kit** was in stock at n-Factory when ordered; two other shops 404'd the same week.
- Buy the **patch in the connector variant that matches your pigtail** — the order log caught
  an RP-SMA/SMA mismatch at checkout.
- **HDZero receivers churn**: BoxPro was sold out at one shop; a used HDZero goggle/VRX from the
  classifieds is the cheapest first picture. Analog goggles **cannot** receive HDZero at all.
- Sender hardware total (without receiver): **~€ 410–450** as ordered.

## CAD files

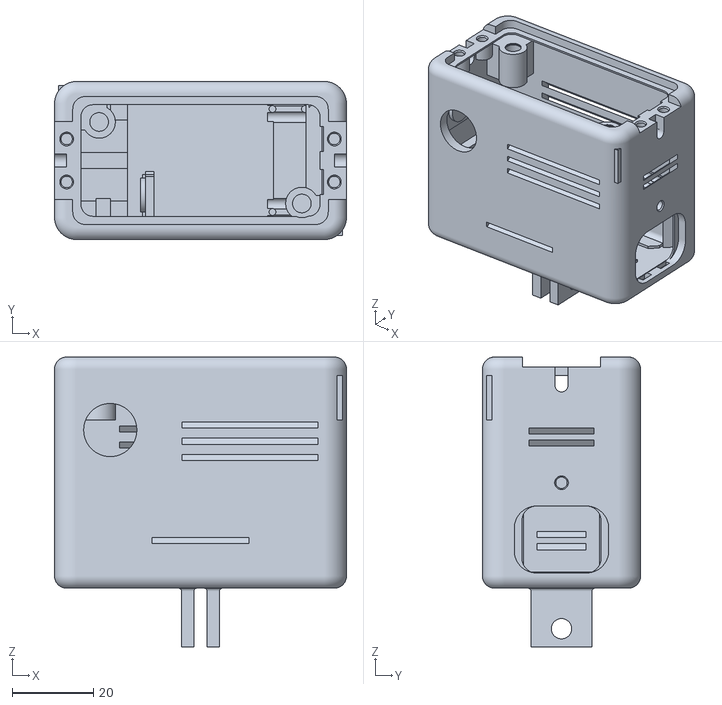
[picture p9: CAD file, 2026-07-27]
build/stl/skylive_mid_body.stl
72.0 x 39.0 x 71.5

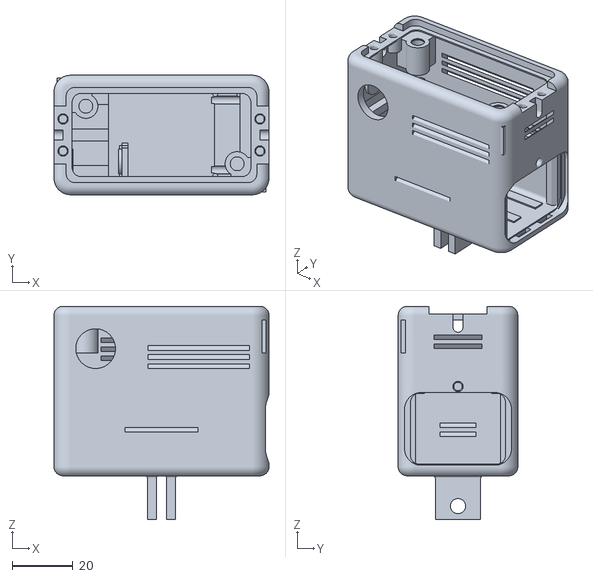
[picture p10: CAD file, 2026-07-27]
build/stl/skylive_V3_min_body.stl
71.0 x 39.5 x 70.5

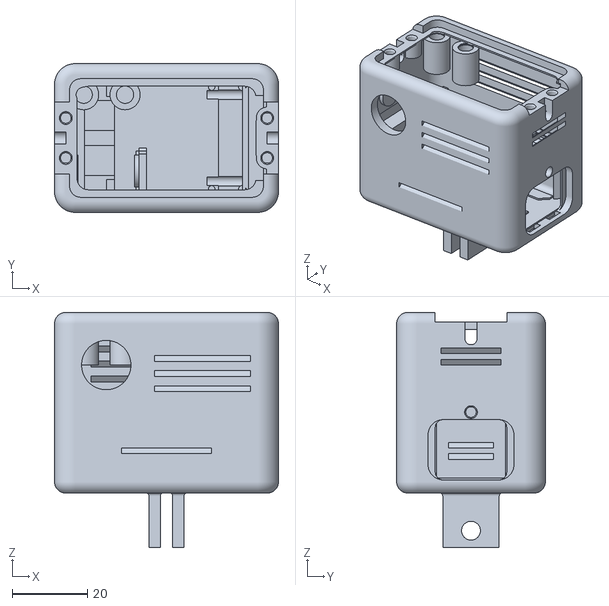
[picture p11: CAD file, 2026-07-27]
build/stl/skylive_mini300_body.stl
59.5 x 39.5 x 62.5

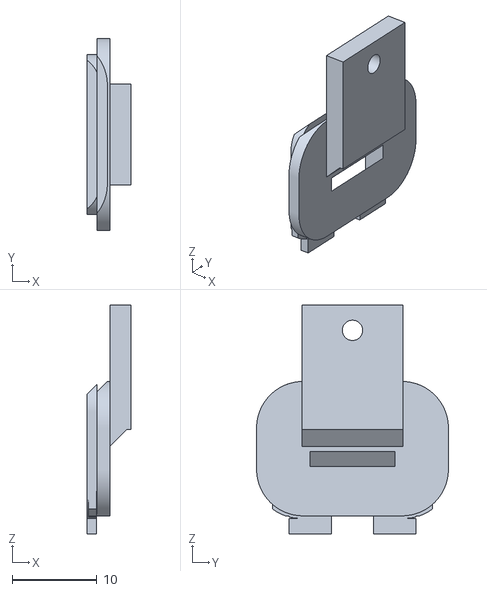
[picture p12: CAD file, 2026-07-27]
build/stl/skylive_mid_battery_door.stl
5.20 x 22.7 x 27.1

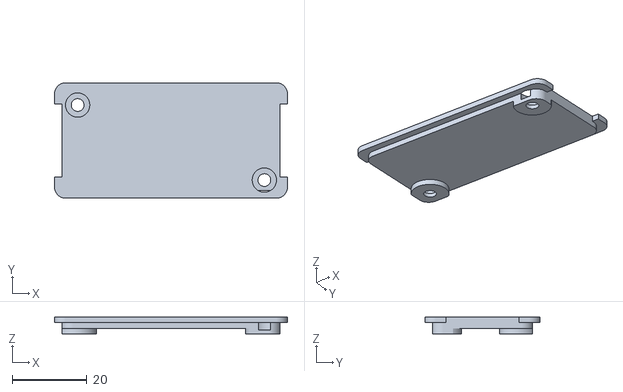
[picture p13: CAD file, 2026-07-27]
build/stl/skylive_mid_cover_floor2.stl
62.4 x 30.9 x 4.50

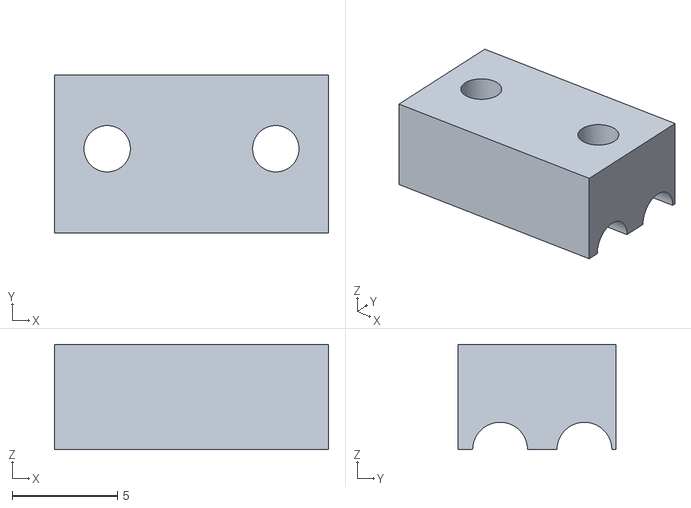
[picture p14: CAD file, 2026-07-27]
build/stl/skylive_mid_xt30_latch.stl
13.0 x 7.50 x 5.00

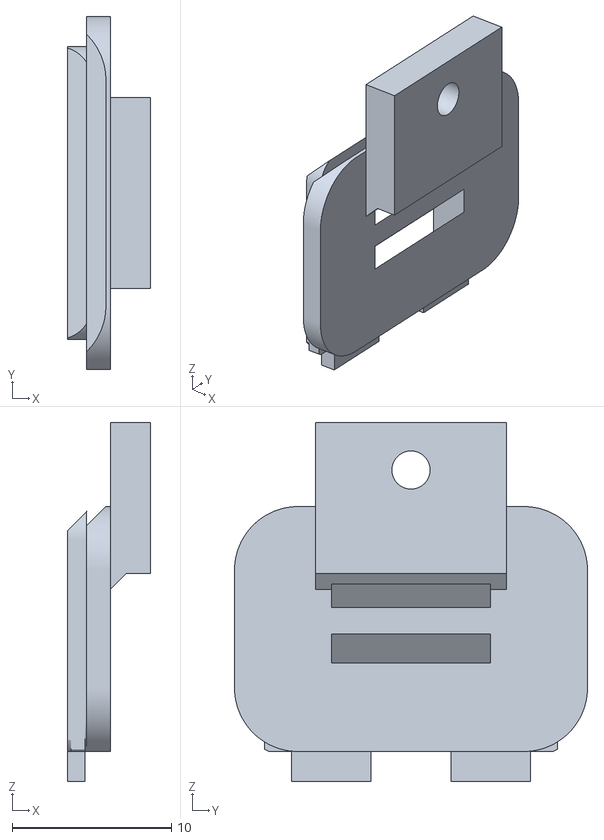
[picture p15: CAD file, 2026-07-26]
build/stl/skylive_mini300_battery_door.stl
5.20 x 22.2 x 22.6

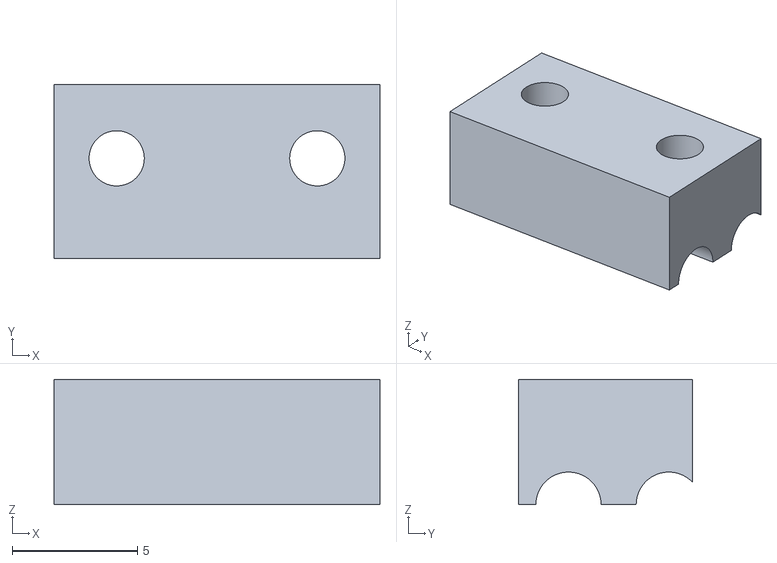
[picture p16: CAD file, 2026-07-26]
build/stl/skylive_V3_min_xt30_latch.stl
13.0 x 6.95 x 5.00

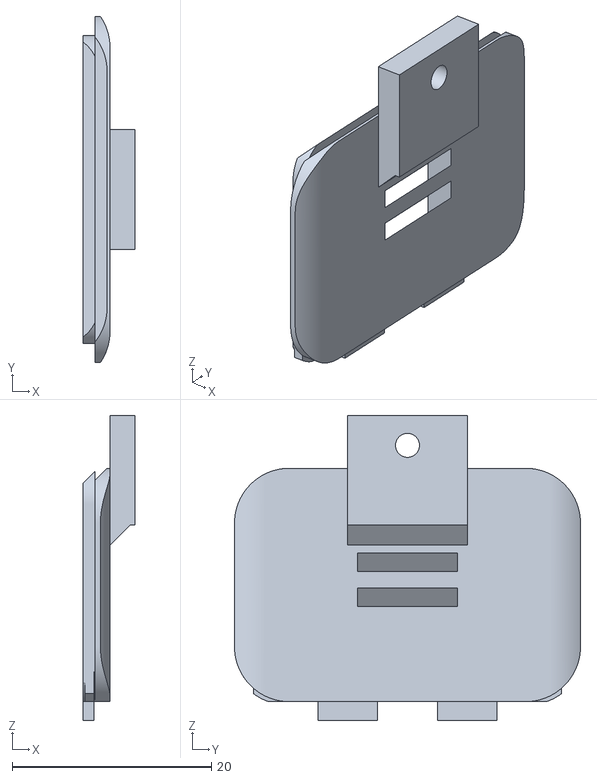
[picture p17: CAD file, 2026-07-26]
build/stl/skylive_V3_min_battery_door.stl
5.20 x 34.7 x 30.6

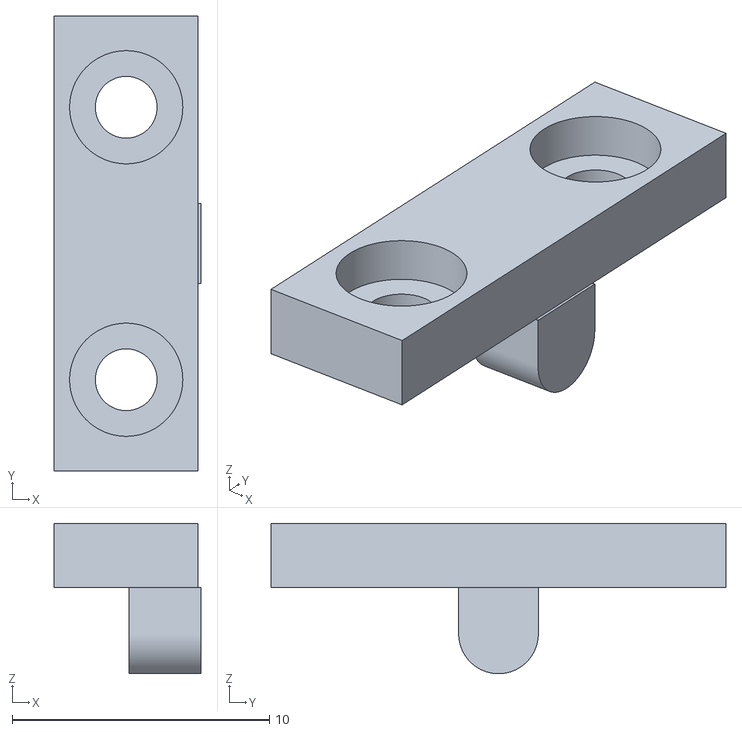
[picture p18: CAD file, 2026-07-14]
build/stl/skylive_V3_min_ze_tee_flush.stl
5.70 x 17.7 x 5.85

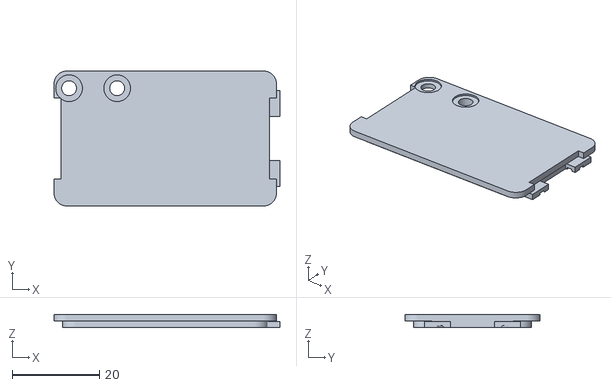
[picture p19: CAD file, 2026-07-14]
build/stl/skylive_mini300_cover_floor2.stl
51.7 x 30.9 x 3.00

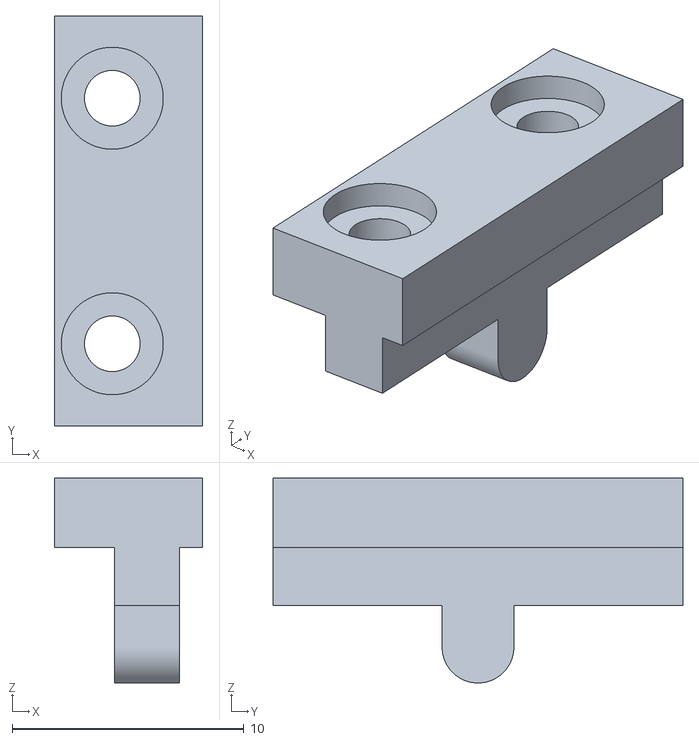
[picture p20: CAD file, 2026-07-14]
build/stl/skylive_mini300_ze_tee.stl
6.40 x 17.7 x 8.85

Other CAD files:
build/stl/skylive_V3_min_cover_floor2.stl
build/stl/skylive_mini300_xt30_latch.stl

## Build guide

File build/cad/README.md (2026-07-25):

# SkyLive CAD — parametric, gated, honest

> **Status: the V3 family builds and passes all geometry gates** — three sizes, one
> architecture, upright two-storey shells: **850** 71 × 40 × 56 mm (flight unit) ·
> **mid** 71 × 38 × 48 mm · **Mini 300** 59.5 × 39.5 × 48 mm. Watertight, 3 mm wall,
> printability gate on every export. Still open before a part is *trusted*: the physical
> tests — a CAD boolean is not a test. Read, run, tweak.

## The files

| file | role |
|---|---|
| **`spec.py`** | **Single source of truth for every dimension** (~185 parameters). Each value is (a) measured from an official manufacturer STEP, (b) sourced from a datasheet/vendor page (URL in the comment), or (c) listed in `MEASURE_ME` with a documented fallback. Nothing is estimated. CAD, docs and renders all import from here — no drift. |
| **`v3_min.py`** | Builds the **850 flight unit**: one-piece two-storey body (battery downstairs, radio + camera upstairs — the divider shelf is printed in), tab-locked battery door on a brass-insert screw, roof lid on 3 corner inserts, 2× XT30 clamp bar, 2× strain-relief T-piece. Camera bulge inverted 1:1 from a measured reference print. Hard gates on every rebuild. |
| **`mid_sender.py`** | The **mid sender** — the same architecture around the smaller Tattu 300 3S HV pack (measured 45 × 17.5 × 15.3). |
| **`mini_300.py`** | The **Mini 300** — smallest port of the same architecture; no power switch (floor 2 has no room for one — power = plug the battery). |
| **`printability_gate.py`** | Mesh-level print gate run before every STL export: knife-edge / vanishing-wall detection (FAIL), overhang clusters, enclosed voids, sliver triangles — the failure class a solid-level boolean gate cannot see. |
| **`skylive_sender_v2.py`** | **Legacy** — the earlier V2 case (side-capsule omni and down-patch studies, 63 × 71 footprint). Kept because its derivations are referenced from [`../ENGINEERING/`](../ENGINEERING/); superseded by the V3 family above. |
| **`render_glb.py`** | Blender headless render rig (Cycles CPU): auto-framing, studio light, PBR materials inferred from the per-part colors. |

## How to build

```bash
python -m venv .venv && source .venv/bin/activate
pip install build123d==0.10.*        # tested with build123d 0.10 on Python 3.13
python v3_min.py          # 850 flight unit
python mid_sender.py      # mid sender
python mini_300.py        # Mini 300
# outputs → ../skylive_out/ (created next to the script's parent tree)
```

**You also need the two official manufacturer STEP files** (not redistributed here — fetch
them from the manufacturer's published CAD):

```
references/HDZero Freestyle V2 VTX.step
references/HDZero_Nano90.stp
```

placed relative to the path in `spec.VTX_STEP` / `spec.CAM_STEP` (adjust those two lines to
your layout if needed). The script imports the real VTX and camera solids and positions the
case around them — that is the point: the electronics are real geometry, not gray boxes.

Renders (optional, Blender ≥ 4.x):

```bash
blender --background --factory-startup --python render_glb.py -- \
    ../skylive_out/skylive_A_ASSEMBLY.glb out_renders skylive_A iso,front,side
```

## Design rules baked into the scripts

- **Wall 3.0 mm — sacrosanct.** The only exceptions: the bulkhead counterbore (2.8) and the
  1.5 mm RF radome windows. Ledges, ribs and channels are *additive* — the wall is never grooved.
- **Gates fail loudly.** A build that isn't watertight, collides, or drifts from `spec.py`
  raises an assert instead of silently exporting garbage.
- **`MEASURE_ME` over guessing.** If a vendor doesn't publish a dimension, the parameter
  carries a documented fallback and a caliper instruction (see [`../MEASURE.md`](../MEASURE.md)) —
  it is never quietly invented.
- Print doctrine (orientation, tolerances, shrink, coupons): [`../ENGINEERING/print.md`](../ENGINEERING/print.md).

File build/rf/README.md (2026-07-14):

# RF link analysis — helmet sender, donut orientation

*Condensed from the project's full analysis (`RF_ANALYSIS_DONUT`, model v1.0, 2026-07-01).*

> **THIS IS A CALCULATION / LINK-BUDGET MODEL, NOT A MEASURED TEST.** Every number comes from
> textbook formulas and literature ranges — no jump, no spectrum analyzer, no measured pattern.
> It says *where to look*, it proves nothing. The verification list is at the bottom.

> **Link model v1.0 note.** The RX gains below reflect the **interim store-bought ground
> station** (aimed patch + omnis). The current ground-station doctrine is several fixed beams
> of self-printed helix antennas (estimators span 10.7–13.9 dBic — measurement decides); a
> helix-based link model follows **after measurement D1**, rather than silently editing these
> numbers.

**Companion tool:** [`linkbudget_donut.html`](linkbudget_donut.html) — an interactive,
self-contained explorer (open it in any browser, no install). Play with altitude, drift,
pose and orientation and watch the margin.

## 1 · System parameters (sourced / given)

TX **+30 dBm** (1 W, HDZero Freestyle V2) · 5.8 GHz · TX cabling **−1.5 dB** · TX antenna
AXII 2 RHCP omni, **+2.2 dBic peak** · RX main: aimed patch used at an **honest +10 dBic**
(nominal 13) · RX diversity omnis +4.7 / +1.9 dBic (4-way receiver) · RX cable −1 dB ·
lock threshold **−90 dBm** (HDZero degrades gracefully a few dB below).
FSPL (Friis): **119.8 dB at 4 km**.

## 2 · The key correction to intuition

An omni's peak gain is **fixed** at +2.2 dBic no matter how you orient it. Turning the antenna
does not add power — it only re-points where the peak and the null go. Laying the puck
horizontal (axis pointing through the case wall) doesn't "transmit more downward"; it **aims** the same donut
at the ground station instead of wasting it on a horizontal ring. In freefall over the DZ the
ground station sits at down-angles of 63–83° — deep in the down hemisphere — so:

| altitude (500 m drift) | up/down donut advantage over an upright antenna |
|---|---|
| 4 km | **+17.9 dB** |
| 3 km | +17.5 dB |
| 2 km | +13.9 dB |
| 1 km | +7.3 dB |

**Do not stand the antenna vertical.** (The upright case even had its null-axis placed at the
least favourable azimuth — the delta above is conservative.)

## 3 · Body shadow (the honest crux)

Radio does not pass a human well. On-body literature at 5.8 GHz: torso deep-shadow −10…−18 dB,
head −6…−12 dB, with diffraction relief at body edges. A side-mounted element ~3–5 cm off the
head centreline buys a few dB back. Used values (side-mount): **head-down −1 dB · back-fly
−7 dB · belly −10 dB · sit −12 dB.** Body shadow is body geometry — identical for both antenna
orientations, and the **single biggest uncertainty in the whole model**.

## 4 · Margins at 4 km (dB above −90 dBm, up/down donut, honest RX gain)

| pose | 4 km | 3 km | 2 km | 1 km |
|---|---|---|---|---|
| **Head-down** | **+8.8 ✓** | +11.2 ✓ | +14.3 ✓ | +18.6 ✓ |
| **Back-fly** | +2.8 ⚠ | +5.2 ⚠ | +8.3 ✓ | +12.6 ✓ |
| **Belly** | **−0.2 ✗** | +2.2 ⚠ | +5.3 ⚠ | +9.6 ✓ |
| **Sit** | −2.2 ✗ | +0.2 ⚠ | +3.3 ⚠ | +7.6 ✓ |

What closes the thin cells: the patch's nominal gain if it delivers (+3 dB everywhere) ·
4-way ground diversity catching pose transitions · **descent** (2–3 dB per km, within seconds) ·
HDZero's usable picture a few dB below lock. What must be proven: the sit/high-altitude corner.

## 5 · Assumptions & their direction of error

FSPL only (no multipath — ground reflections near the DZ swing ±several dB) · shadow values are
literature midpoints, not this helmet · ideal-dipole toroid floored at −18 dB (the real CP
pattern is rounder — narrows the delta, doesn't flip the sign) · RX patch assumed aimed
(a lost aim costs up to 10 dB instantly — the omnis are the backstop) · RHCP↔RHCP matched.

## 6 · Verify before trusting (in order)

1. **VNA S11 of the antenna with its coax in the printed clamp** (instrument must cover 5.8 GHz).
2. **Bench range test** (antenna on a pole, walk the RX out) — isolates FSPL+antennas from body shadow.
3. **A real jump with a logging ground station**: RSSI vs altitude/pose vs these cells — one
   belly pass from 4 km validates or kills the −10 dB shadow assumption.
4. **Diversity switching in situ** on pose transitions.

*No superlatives. The result is: up/down is clearly the right orientation for a below-you
ground station; head-down and descending belly close comfortably; the head-up/high-altitude
corners are the ones to prove with a real jump.*

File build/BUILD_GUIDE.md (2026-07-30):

# SkyLive — Build Guide (soldered flight build · Wago quick-build)

> **Wiring doctrine (updated):** the **soldered build is the recommended flight configuration** —
> every lead cut to its actual run length (shorter cables = less weight, less rattle, fewer
> failure points). The Wago 221-412 path below stays as the excellent **zero-solder quick-build**
> for a first assembly and for iterating. Everything else on this page applies to both.

*Condensed English edition of the project's German build document (`BAUANLEITUNG`, 2026-06-29,
specs verified against HDZero documentation). Status: the electronics build below is bought,
specified and wiring-verified on paper; the printed case passes its geometry gates in all
**three sizes** — **850** 71 × 40 × 56 mm (flight unit) · **mid** 72 × 39 × 57 mm ·
**Mini 300** 59.5 × 39.5 × 48 mm.
The STEP/STL files build from [`../cad/`](../cad/). **Nothing here carries a "measured" badge yet —
the first print is a fit prototype, and a handful of values are still datasheet fallbacks.***

> ⚠️ Read [`LEGAL_DE.md`](LEGAL_DE.md) before transmitting anything. In Germany, all testing
> happens at **25 mW** under the licence-free SRD general authorization; 1 W needs a PMSE
> short-term assignment (event) — see the doctrine there.

---

## 1 · The system — two devices

| device | purpose | core |
|---|---|---|
| **Sender** (helmet) | 1 W live video from freefall (up to 4 km) | HDZero **Freestyle V2** VTX + **Nano90** camera · 3S LiPo · standalone — **no flight controller, no BEC** |
| **Ground station** (DZ) | receive + public viewing | HDZero **BoxPro** (4-antenna diversity, Mini-HDMI out) + **several fixed beams** — self-printed helix antennas, zenith + horizon (§ 9) |

## 2 · Sender parts

- **HDZero Freestyle V2 VTX** — 1 W, input 7–25 V (2–6S), 6–15 W draw, U.FL antenna output, **no reverse-polarity protection**
- **HDZero Nano90 camera** + 20-pin **MIPI cable** (fragile — powered by the VTX over MIPI)
- **Tattu R-Line 3S 850 mAh** (XT30 + JST-XH balance) — smaller 2–3S packs work too, only shorter airtime
- **12 mm latching push-button** (2 A / 12–250 V, pre-wired) — carries the ~1.3 A directly in the + line
- **3× Wago 221-412** lever clamps (0.14–4 mm²) — the entire power wiring *on the quick-build path*
  (the flight build solders these joins instead, § 4)
- **U.FL→SMA flange pigtail** (e.g. TBS, 60 mm) — fixed once, protects the fragile U.FL
- **Antenna (5.8 GHz, RHCP):** the donut omni (Lumenier AXII 2), captive against the short case
  wall under the screw-driven T-clamp — axis horizontal, straight through the wall. *(A down-firing
  patch and a fully encapsulated capsule exist only as legacy studies —
  [`ENGINEERING/antenna_capsule.md`](ENGINEERING/antenna_capsule.md).)*
- **Thermal pad** 1.5 mm, ≥ 3 W/mK, VTX face → case wall (mandatory — see doctrine, § 7)
- **Printed case** — PETG for fit prototypes, **ASA for the final part, never PLA** (`TBD-CAD-M6`)

Tools/consumables: **multimeter (mandatory — polarity check)**, heat-shrink, RTV/hot glue
(secure the Wago levers + strain relief), zip ties, a 50 Ω SMA dummy load (safe bench testing).

## 3 · Connector facts (verified)

- **VTX harness = JST-GH 1.25 mm, 6-pin.** Pinout:
  **Black = GND · Red = Power (+) · Yellow = RX · White = TX · Blue = SmartAudio** (one pin free).
  Standalone video needs **only Red + Black**. The harness plugs into the VTX — no soldering.
- **Battery: XT30** (battery female → pigtail male). Charging (3S): XT30 **and** JST-XH balance
  both into a balance charger; XT60→XT30 adapter if needed.
- **Antenna rules:** U.FL on the VTX = **~30 mating cycles, fragile** → plug it once into the
  flange pigtail and never touch it again; all swapping happens at the **SMA** (≥ 500 cycles).
  **SMA ≠ RP-SMA** (they thread together but don't connect) — check every plug pair.
  All 5.8 GHz antennas **RHCP on both ends** (mixing polarizations costs the link).

## 4 · Wiring — one map, two paths

```
Battery XT30 ── XT30-female pigtail (+) ──[joint]── switch ──[joint]── VTX red (+)
                XT30-female pigtail (−) ──[joint]───────────────────── VTX black (GND)
                VTX yellow/white/blue → heat-shrink caps (unused)
Camera ── MIPI ──→ VTX          VTX U.FL ── U.FL→SMA flange pigtail ── antenna
```

Each `[joint]` is either a solder joint or a Wago — the topology is identical.

**Path A — soldered (the recommended flight configuration):** cut every lead to its true run
length, solder + heat-shrink each joint. Shorter cables, less weight, nothing to rattle, no
lever to work loose.

**Path B — Wago quick-build (great first assembly):**
1. Plug the JST-GH harness into the VTX. Take red + black (bare ends).
2. **Three Wago 221-412:** + line = pigtail(+) ↔ switch ↔ VTX red (2 Wagos);
   − line = pigtail(−) ↔ VTX black (1 Wago). Thin strand wobbly? **Fold the end double** —
   no ferrule, no crimper needed.
3. Secure the Wago levers with a dab of RTV/hot glue (vibration) + strain relief (§ 5).

Either path: connect antenna (U.FL → flange pigtail, once) and camera (MIPI).
**Antenna on BEFORE power — always.**

> No capacitor needed — there are no motors, the supply is clean.

## 5 · Strain relief (consumer-safe)

Principle: *pull on the battery cable is absorbed by the case before it reaches any connection.*

1. **Stopper hole (passive):** route the cable so the thin wire passes but the thick spot
   (XT30/heat-shrink bulge) cannot — a pull seats the bulge against the wall. Idiot-proof.
2. **Zip-tie anchor** around the cable jacket through two printed webs.
3. **Service loop** (slack loop inside).
4. **90° anti-kink boot** over the pigtail transition.

(All four are designed into the case CAD — cable channel, stopper step, zip-tie webs. `TBD-CAD-M6`)

## 6 · 🚨 Hardware killers (never skip)

1. **NEVER power the VTX without an antenna or a 50 Ω dummy load** — reflected power kills the PA instantly.
2. **Check polarity with a multimeter before first power** — the Freestyle V2 has **no reverse-polarity
   protection**. VTX red must read +11–12.6 V. Red = +, black = −.
3. **PETG/ASA case + thermal pad VTX→wall** — at 1 W the VTX reaches ~90 °C in ~2 minutes in a
   closed case on the bench. It is the hottest part in the box.
4. **U.FL ≈ 30 mating cycles and fragile** — seat it firmly, secure with a dab of hot glue,
   never unplug it for fun.
5. **The JST-XH balance plug is for charging only** — never toward the VTX.

## 7 · Power & thermal operating doctrine (BINDING — derivation: [`ENGINEERING/thermal.md`](ENGINEERING/thermal.md))

At 1 W RF the VTX dissipates **~13–14 W as heat** — on the ground, in still air, that is
**not passively removable** (no vent geometry changes that; over-temperature = a hard RF cut
by the VTX "until repowered" = picture gone until you cycle the switch). Therefore:

| phase | power | why |
|---|---|---|
| Ground / waiting / climb | **25 mW** (pit mode usually suffices) | continuously coolable (chimney vents) |
| 200 mW on the ground | **max. 10 min** (≈ 5 min at a 35 °C summer DZ) | borderline |
| **Door open / exit call** | **only now 1 W** (set via the ground station) | from exit, ram-air cools with 4–8× reserve |
| After landing | **OFF within 60 s** | hot start + still air = the second worst case (~2–4 min to cut-out, calculated) |

The 1.5 mm thermal pad VTX→side wall is mandatory: on the ground it only moves ~0.6 W, but it
doubles the effective heat capacity (buys 1–2 minutes in the power-up window) and carries
~2.5 W in freefall as a second path.

## 8 · Charging & first start

- **Charging (3S):** balance charger, XT30 **and** JST-XH both connected, ~1C, LiPo 3S mode.
  Never without balance, never on a 1S charger. LiPo bag recommended.
- **First start:** antenna on → battery in → the VTX boots in **pit mode (0 mW)** → set channel
  and power via the **ground-station (BoxPro) menu**. 1 W requires the unlock — mind the licence
  situation ([`LEGAL_DE.md`](LEGAL_DE.md)). Watch the heat; lowest usable power on the ground.

## 9 · Ground station — several fixed beams, no tracker

- Doctrine: **the gain belongs on the ground — as multiple fixed beams.** A stronger body
  antenna buys ~2–3 dB; a ground beam buys 10+ dB. A tracker has a zenith keyhole exactly
  where the jump is; fixed beams (zenith + horizon) don't, and the receiver fuses the branches.
- **The beams are self-printed axial-mode helix antennas** — 5.8 GHz, RHCP, 7 turns, C/λ 1.00,
  pitch 10.5°, **cup reflector with copper tape inside** (the higher-gain cone loses in the
  minimax over the real jump geometry despite +4 dB peak), HPBW ~37°. Gain, honestly:
  **estimators span 10.7–13.9 dBic — measurement decides.** Print ASA, never PLA (Tg).
- **Ball-head mount** — elevation is set in the field, not baked into a printed angle.
- **HDZero BoxPro** — 4-way diversity, Mini-HDMI straight to the public-viewing TV.
  **Unscrew the stock 2 dBi linear stubs**: HDZero fuses branches by data integrity, it does
  not pick the best — one bad branch degrades the whole picture.
- **Wi-Fi scan the drop zone before operating** — the 5.8 GHz video channels overlap Wi-Fi;
  a nearby access point raises the noise floor more than any antenna gain can buy back.
- The store-bought set (aimed patch + two omnis) remains the labelled **interim/comparison
  station** until the helix branches are measured.

## 10 · What you must measure yourself

Nothing in this project is guessed. Before printing/final assembly, work through
[`MEASURE.md`](MEASURE.md) — caliper dimensions, S11 of the antenna with its coax clamped, and
the thermal A/B test are all listed there with instructions.

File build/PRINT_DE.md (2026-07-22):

# SkyLive Sender 850 — Druckanleitung (Labor-fertig)

Mini-Vents · GoPro-Zähne 3,0 · 1 langer Bay-Schlitz Kamera-Seite), alle STLs frisch aus dem
verifizierten CAD (alle Gates grün; Export 08:23, **02_deckel NEU 07-06 nachmittags** —
Kopf-Auflage-Fix nach Toms Fund, s. unten). 5 Dateien, Riegel + T-Stück 2× drucken → **7 Teile
gesamt**. Ehrlich: CAD-verifiziert, ERSTER Fit-Druck — Passungen (Tür, Deckel, Inserts, GoPro,
ZE-Presssitz) am Teil prüfen, Werte rückmelden.*

> **Was sich seit der ersten Freigabe geändert hat (Body + Klappe + Teil 05):**
> **(1) Antennen-ZE = DIE REFERENZ-MECHANIK (T-Prinzip 2.0, 07-06 abends — der Einwand
> „das Kabel soll GANZ RUNTER und VOLL eingeklemmt werden" + STEP-Vermessung seines T-Teils
> und Grundkörpers):** Der Sitz in der Wand hat **SPIEL** (Ø3,2 auf Ø3,1 — Referenz-Maß, mein
> früherer „2,9-Presssitz" war eine Fehldeutung!). **Die Klemmkraft kommt von den Schrauben:**
> das T-Stück hat einen Steg mit **konvexer Nase R1,55** (= Kabelradius), die 2× M2×8
> VERTIKAL ziehen die Nase **0,4 mm in Presslage** aufs Kabel. Von oben: Mund 18×2,5
> (Querhaupt bündig) → Führungsschlitz 3,3 → Rundsitz Ø3,2 durch die Wand. **KEINE Kerbe,
> KEIN Bohren mehr nötig** — der Steg sitzt ÜBER dem Kabel, der Kabelweg durch die Wand ist
> immer frei. 1 T-Typ, 2× gedruckt, beidseitig identisch — **Seitenwahl bleibt DEINE** am
> Realteil. (Unbenutzte Seite: Mund+Schlitz zu; unterm Nasen-Steg bleiben zwei kleine
> Ø3,2-Sichel-Öffnungen des Sitzes — ehrlich gesagt: Mini-Vents, kein Loch.)
> **(2) Akku-Klappe SCHLICHT:** der alte Innen-Schraubboss hätte mit dem Akku kollidiert
> (60+1 Swell endet bei 28,5 — Boss begann bei 26,5; der Einwand war richtig, jetzt per
> Gate bewiesen frei). Neu: bündige Platte + **Lasche oben mittig** (1× M2 in Wand+Shelf,
> null Innenraum-Anspruch) + 2 Fuß-Nasen. Griffmulde entfällt — die Lasche ist der Griff.

## Material

| Zweck | Material | Warum |
|---|---|---|
| **Morgen (Fit-Prototyp)** | **PETG** | zäh genug für Klick/Zähne, einfach, maßhaltig genug |
| Final (Außeneinsatz) | **ASA** | UV-fest + formstabil bis ~95 °C (VTX-Wärme + Sonne am Helm). **Nie PLA** (erweicht) |

## Slicer-Grundeinstellungen (PETG, 0,4er Düse)

- **Schichthöhe 0,20 mm** · **4 Perimeter** (Schraub-/Klemm-/Zahn-Zonen brauchen Fleisch!)
- **Infill 40 % Gyroid** · Deckschichten 5 oben / 4 unten
- Temperatur nach Filament (typ. PETG 235–245 °C / Bett 75–85 °C)
- **Bauteilkühlung MAX 40–50 %** — PETG-Layerhaftung ist die Festigkeit der GoPro-Zähne!
- Naht: „Hinten" (auf die +Y-Rückseite legen)
- Elefantenfuß-Kompensation 0,15 (bündige Falze!)
- **Keine automatischen Supports** — nur die unten je Teil markierten Zonen (paint-on)

## Ausrichtung je Teil (WICHTIG — Layer-Richtung = Festigkeit)

### 01_body.stl — **AUF DIE RÜCKSEITE (+Y) LEGEN** (die Wand mit den 3 langen Schlitzen nach unten)
**Warum:** So liegen die **GoPro-Zähne HORIZONTAL** → Layerlinien laufen LÄNGS der Zähne →
Biegekraft beim Einclipsen läuft **mit** den Layern statt quer = deutlich bruchfester (dein Punkt!).
Zusätzlich: Kamera-Front zeigt nach oben (sauberste Sichtfläche), der fest verbaute Shelf steht
vertikal (druckt supportfrei), Dach-Öffnung zeigt zur Seite.
- **Support (paint-on) NUR an:** GoPro-Gabel-Unterseite (kragt seitlich aus) · die 3 Eck-Bosse
  (kragen horizontal) · Tür-Falz-Oberkante innen · Kamera-Ösen-Querbohrung ist Ø2,4 → supportfrei ok
- Die 45°-Louver der liegenden Rückseite werden zu Bett-Kontakt-Schlitzen → 5 mm **Brim** um die
  Wand-Auflage, Schlitz-Ränder nach dem Druck kurz entgraten.
- Ehrlicher Trade-off: liegend braucht der Body etwas Support innen — dafür sind Zähne + Klick-
  Nasen der Tür in der starken Richtung. Aufrecht wäre supportärmer, aber Zähne = Layer-gestapelt
  = Sollbruchstelle. **Zähne gewinnen.**

### 02_deckel.stl — **flach, Außenseite nach UNTEN** ⚠ NEU 07-06 abends: DIE REFERENZ-SENKUNG
Kein Support nötig (die 3 Unterseiten-Pads Ø10×1,5 drucken als flache Zylinder oben auf).
**Die Ansage „übernimm das vom Referenz-Prototyp" umgesetzt — sein Deckel.STEP vermessen:** CB **Ø6,5 ×
3,4**, Durchgang Ø3,4, **Kopf versenkt 0,4 unter bündig**, tragender Boden 1,1 (exakt des Referenz-Prototyps
Werte). Sein Deckel ist 4,5 dick — unserer holt die Dicke über **lokale Pads an der
Unterseite** (Deckel misst an den Schrauben 4,5, sonst 3,0). Dafür: Bosse 1,5 gekürzt +
Schrauben 1 mm diagonal einwärts (±28/±12 — sonst ragt der versenkte Kopf in die Falz-Ecke;
per Gate bewiesen). **Der Fund #1 bleibt dokumentiert:** die Ur-Datei hätte den Kopf komplett
durchfallen lassen. Deckel aus einer älteren Datei = wegwerfen, nur diese gilt.

### 03_akkuklappe.stl — **flach, Außenseite nach UNTEN**
Kein Support. Die Nasen liegen horizontal → Layer längs = stabil beim Einhängen/Kippen.
Die 2 Mini-Louver drucken bei dieser Lage supportfrei (45°-Eigenüberhang).

### 04_xt30_riegel_2x.stl — **2× drucken**, flach auf die HUTDECKE (Fuß + Rinnen nach oben)
**v2 (07-22, Hutprofil):** Gesamthöhe 5,0 (v1 3,0 war vom Brim kaum zu unterscheiden), der breite Hut
umschließt beide M2-Bohrungen voll (v1 hatte halboffene Kerben an den Enden). Supportfrei in dieser Lage.
**Achtung:** seit dem Rinnen-Fix 07-14 ist der Riegel **modellspezifisch** — Zwischengröße hat eigene
Rinnengeometrie (`skylive_mid_xt30_latch.stl`), 850er + Mini teilen `skylive_V3_min_xt30_latch.stl`.
Kein Support. Klein — beide nebeneinander aufs Bett.

### 05_ze_t_stueck_2x.stl — **2× drucken** (+1 Reserve), flach auf den Rücken (Nase oben) ⚠ NEU 07-06 abends
**die Referenz-Mechanik 1:1** (sein T-Teil STEP-vermessen): Querhaupt 17,7 × Steg 3,1 mit
**Rundnase R1,55**. Einbau: Kabel von oben in den Schlitz ganz runter bis in den Ø3,2-Sitz
drücken (geht LEICHT — der Sitz hat Spiel, das ist richtig so!) → T einschieben, Nase aufs
Kabel → **2× M2×8 anziehen = DIE Klemmung** (die Schrauben ziehen die Nase 0,4 ins Kabel).
Nichts bohren, nichts kerben. Beide Seiten identisch; Seitenwahl deine. Falls das T nicht
leicht in Mund/Schlitz einfährt: Maß melden statt feilen.

## Nach dem Druck (Reihenfolge!)

1. **Messing-Inserts ZUERST einschmelzen**, solange das Gehäuse leer ist (Lötkolben 250–270 °C,
   senkrecht ansetzen, langsam sinken lassen, 0,3 mm unter bündig stoppen. Fehlerbild: schiefer
   Insert/Blob = zu heiß oder zu schnell):
   - **3× M3 (Ø5×6)** in die Dach-Bosse, von oben
   - **1× M2 (Ø3,2×3 — deine Messung)** in die Ø2,8-Bohrung ÜBER der Akku-Öffnung (Achse
     horizontal, von außen — die Lasche deckt den Insert-Mund später ab). Tür-Schraube = M2×6.
2. Fit-Checks: Tür einschieben (unten Nasen einhaken → ankippen → M2) · Deckel auflegen (Lippe
   taucht ein, 3× M3) · GoPro-Mate auf die Zähne (**3,0 — Toms Vorgabe 07-06**; falls stramm:
   NICHT feilen, Wert melden) · Kamera einsetzen (linke Schraube von außen durch die
   Wand-Einsenkung!) · XT30-Adern (Ø2,8) in die Sattel-Rinnen legen, Riegel schrauben ·
   **ZE (T-Prinzip 2.0, kurze Seiten — DEINE Seitenwahl):** Koax von oben durch Mund +
   Schlitz GANZ RUNTER in den Ø3,2-Sitz legen (fällt leicht rein — Spiel ist korrekt; es
   läuft waagerecht durch die Wand, Glocke außen direkt an der Wand) → T-Stück einschieben,
   Nase liegt aufs Kabel → **2× M2×8 vertikal ANZIEHEN = Klemmung** (Nase presst 0,4 ein);
   andere Seite: zweites T identisch + 2× M2×8. Querhaupt oben bündig mit dem Dachrand.
3. Was klemmt/wackelt → kurz notieren (Teil + Stelle + gefühltes Maß) — fließt direkt ins CAD.

**Teile-Übersicht:** Body ~71×39,5×56 · Deckel (dunkel im Viewer) · Klappe (blau, mit Lasche)
· 2 Riegel (grün) · 2× dasselbe ZE-T-Stück (Nasen-Steg — Schrauben klemmen; Seitenwahl deine).
**Schrauben-Einkauf: 3× M3×8 (Deckel) · 4× M2×8 (ZE) · 1× M2×6 (Lasche→M2-Insert) · 4× M2×8 (Riegel) · 2× M2 (Kamera) · Inserts 3× M3 + 1× M2.**
Viel Erfolg im Labor! 🛠️

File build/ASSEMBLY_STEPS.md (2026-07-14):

# SkyLive — Assembly, step by step (the fiddly bits)

*The close-up companion to [`BUILD_GUIDE.md`](BUILD_GUIDE.md). Where the build guide gives you the
system and the wiring map, this file walks the **hand movements** — the ones that go wrong the
first time if nobody warns you. Each step is written as **Do / Why / Watch out (the failure it
produces)**, in the order you actually work.*

*Labels, same discipline as the rest of the repo: sourced numbers carry their origin, **[CALC]** =
calculated, `MEASURE_ME` = you must caliper your own part, **`TBD-ASSET`** = a photo/render or a
still-open, model-dependent number that lands when the final CAD pass closes. **Nothing here
carries a "measured" badge yet** — the reference prototype prints and fits; the numbers below are
spec-locked, not bench-proven. A CAD boolean is not a test.*

> ⚠️ Read [`LEGAL_DE.md`](LEGAL_DE.md) before any transmit. All development is **25 mW SRD**;
> 1 W is the event-only PMSE path. And read the three hardware-killer rules in
> [`BUILD_GUIDE.md` § 6](BUILD_GUIDE.md#6--hardware-killers-never-skip) before you power anything.

---

## Before you start — the two-minute inventory

The four functional parts (VTX, camera, battery, switch), the **U.FL→SMA flange pigtail**, the
donut omni, the **1.5 mm thermal pad**, and the printed parts: **body** (one piece — both
storeys and the divider shelf print as one), **roof lid**, **battery door**, **2× XT30 clamp
bar**, **2× strain-relief T-piece**. Plus the small-parts bag (**M2 & M3 brass heat-set inserts,
M2 & M3 DIN 912 cap screws**) and the tools: **soldering iron** (inserts, the XT30, and — on the
recommended flight build — the power joins; the Wago quick-build path needs **3× Wago 221-412**
instead), a multimeter, an 8 mm wrench for the SMA, hot glue/RTV, a caliper.

> Order note: seat the **heat-set inserts first** (they need a hot iron and an empty shell),
> then do all the cold work. Never run the iron near a seated battery or the VTX.

*(Photo lands with the first physical build log — every claim above comes from the executed CAD, not a stock image.)*
---

## Step 1 · Melt the brass inserts (3× M3 roof posts + 1× M2 door latch)

**Do.** The shell prints with **Ø 4.6 mm insert holes** in **Ø 8 mm corner posts** under the roof opening (3 posts — the camera owns the fourth corner),
each with a small **Ø 5.2 × 0.5 mm lead-in chamfer** on top. Set the soldering iron to
**250–270 °C** (rule: print temperature **+10…20 °C** — hot enough to melt PETG, not scorch it).
Sit a brass insert (**Ø 5.0 mm OD × 6.0 mm long**, measured on the reference part) on the chamfer,
put the iron tip **flat into the insert's bore from directly above**, and let *its own weight plus
the lightest push* sink it. Keep the iron **dead vertical**. Stop when the insert sits **~0.3 mm
below flush** (sub-flush, so the lid face seats on plastic, not on brass). Withdraw the iron
straight up; a wet fingertip or a flat cold tool can true the top while the plastic is still soft.

**Also:** one **M2 brass insert (Ø 3.2 OD × 3.0 long, measured)** goes into the **Ø 2.8 hole
above the battery opening** (axis horizontal, set from outside — the door tab covers its mouth
later). Same technique, smaller iron tip. This is the most-cycled thread in the whole device
(every battery swap), which is exactly why it gets brass instead of self-tapped PETG.

**Why.** A cold-pressed insert splits the boss; a heat-set one melts the plastic into its knurl and
locks in. The **Ø 4.6 hole is a deliberate ~0.4 mm undersize** vs the 5.0 insert — the displaced
melt is what grips the knurl. Each **Ø 8 post is welded into its case corner**, so the corner walls
carry the load with it. Sub-flush by 0.3 keeps the sealing face clean.
(All geometry [CALC] from standard heat-set guidance + the measured insert; **fit is
bench-verified pending** the first real melt.)

**Watch out.**
- **Brass blob / plastic welling up over the rim** → iron too hot or pushed too hard. It's sunk too
  far and the boss face is fouled. Back off temperature, let it cool, pare the blob flush.
- **Insert goes in tilted (skew)** → the iron wasn't vertical, or you pushed off-axis. A tilted
  insert cross-threads the M3 later. Reheat, push it upright against a flat block, re-true.
- **Insert won't sink / plastic barely softens** → iron too cold or hole printed under-size; give it
  temperature, not force — forcing a cold insert cracks the boss.
- **Insert spins in the hole afterwards** → over-heated, the melt reflowed too loose. That boss is
  compromised; the honest fix is to plug and reprint, not to glue.

There are **3× M3 inserts** under the roof opening — three corners carry the lid; the fourth
corner belongs to the camera, where the rebate lip holds instead (an asymmetry the reference
prototype shares). The battery bay keeps its own door on the end face.
*(Photo lands with the first physical build log — every claim above comes from the executed CAD, not a stock image.)*
---

## Step 2 · Clamp the antenna coax under the T-piece nose (the screws are the clamp)

*(The anchored omni is the standard build. A down-firing patch and an encapsulated capsule exist
only as legacy engineering studies — [`ENGINEERING/antenna_capsule.md`](ENGINEERING/antenna_capsule.md).)*

**Do.** Both short sides carry the same interface, measured 1:1 off a working reference build:
from the top edge, a **mouth** (18 × 2.5 — the T's crossbar seat), a **3.3 mm guide slot**, and
at the bottom a **round Ø 3.2 seat** passing horizontally through the wall. **Lay the Ø 3.1 mm
semi-rigid coax in from above** (never thread a connector through a closed hole) and let it drop
**all the way down** into the seat — it goes in easily; the seat has clearance *by design*. The
cable now runs horizontally through the wall and out; outside, the **omni sits directly against
the wall, axis horizontal, pointing straight through it** — donut fires down/up/all around
instead of aiming a pattern null at the ground. Now slide the **T-piece** down the slot: its stem
ends in a **convex R 1.55 nose** (exactly the cable radius) that lands on top of the cable.
Drive the **2× M2×8 cap screws, vertical, heads up** — they pull the nose **0.4 mm down onto the
cable**: *that* is the clamp. One T-piece design, printed twice, both sides identical — nothing
to drill or notch, pick either side. On the unused side the T seals the mouth and slot; two
small crescent openings of the empty seat remain under the nose (vent-sized, stated honestly).

**Why.** A screw-driven nose clamp holds by bolt tension, not by print tolerance: the seat's
clearance means the cable never fights its way in (no jacket damage, no detuning on insertion),
and the clamping force is whatever the two M2s deliver — repeatable, serviceable, releasable.
A yank on the antenna loads the printed wall and the bolted nose, never the solder or the
connector. The CAD asserts a 0.4 mm nose engagement (1.15 mm³ interference) on every rebuild —
that's a geometry check; the actual holding force is your pull test.

**Watch out.**
- **Cable slides under firm pull** → screws not torqued, or the nose isn't reaching (cable not
  fully down in the seat). Back the T out, re-seat the cable to the bottom, re-drive.
- **T-piece stops proud of the roof edge** → the nose met the cable early (cable riding high) or
  grit in the slot — never force it; the crossbar must land flush in the mouth.
- **Coax jacket visibly crushed at the nose** → over-torqued. The M2s need firm hands, not
  gorilla torque; the nose is shaped to cradle, not to cut.

Then form the coax's **single 90° bend (R ≥ 8 mm)** once, by hand on the printed jig, and mate the
**SMA** to the internal jack (8 mm wrench, firm — not gorilla-tight). The fragile **U.FL is touched
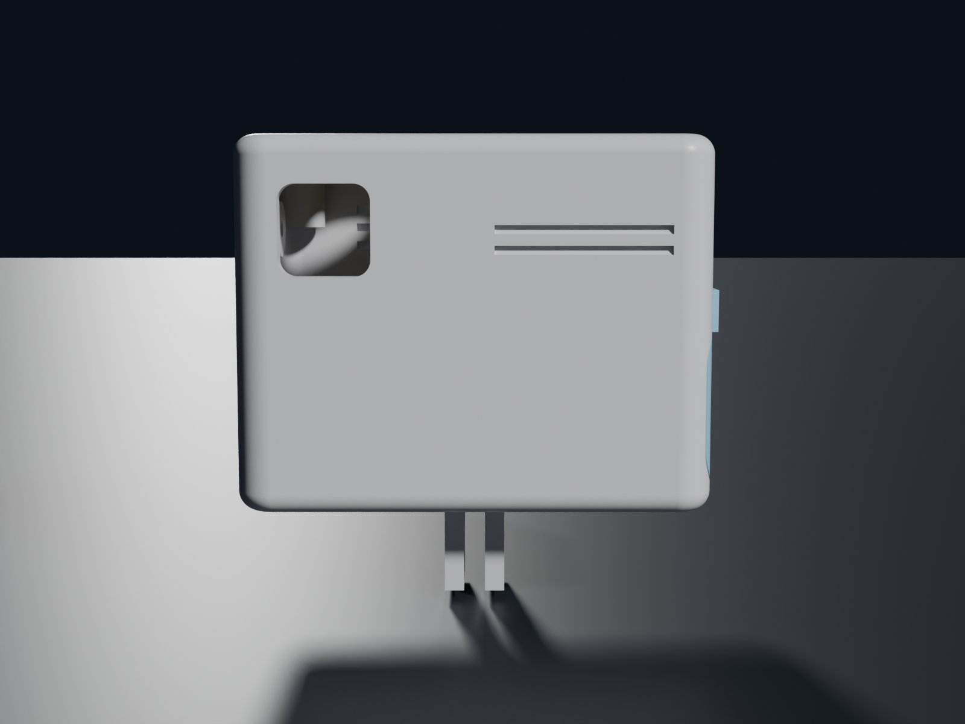
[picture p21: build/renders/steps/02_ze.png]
The T-slot anchor on the short side — slot, T-piece and the two vertical cap screws
exactly once** at the pigtail and never again. 

`DONE-ASSET` — CAD render above; a cross-section →
renders/steps/02_coax_clamp.png; final block dimensions confirm with the CAD pass.

---

## Step 3 · Seat the VTX against the thermal pad

**Do.** Peel one face of the **1.5 mm silicone thermal pad (≥ 3 W/mK)** and stick it to the
**inside of the case wall** opposite the antenna side. Seat the VTX with its **hottest face flat
against the pad**, no air gap, and let the printed shelf/ribs locate it. The VTX is **not** screwed
to the wall — the pad's tack plus the shelf hold it; the wiring dresses last.

**Why.** At 1 W the VTX is the hottest thing in the box (~90 °C in ~2 min in a closed case on the
bench, [CALC]). The pad is a **mandatory** second heat path into the wall — on the ground it only
moves ~0.6 W, but it buys 1–2 minutes in the power-up window and carries ~2.5 W in freefall
([CALC], derivation in [`ENGINEERING/thermal.md`](ENGINEERING/thermal.md)).

**Watch out.**
- **Air gap behind the VTX** → pad not compressed, thermal path is fiction. You should see the pad
  *slightly* squished when seated.
- **Pad on the wrong face** → it must touch the VTX's heat-spreader face, not the connector side.
- **Never bench-power the VTX in the closed case at > 25 mW for more than a minute or two** — it
  will over-temp and RF-cut. That's expected behaviour, not a fault.

*(Photo lands with the first physical build log — every claim above comes from the executed CAD, not a stock image.)*
---

## Step 4 · Camera + MIPI

**Do.** Sit the camera in its printed cradle with the **lens looking out through the wall opening**
(outer face essentially flush/snag-free). Route the **20-pin MIPI ribbon** to the VTX and seat the
connector squarely. The camera is retained from **inside** by an **M2 DIN 912 cap screw** in a
counterbore sized so the head fully sinks (**Ø 4.4 × 2.4 mm counterbore** for the Ø 3.8 × 2.0 mm M2
head — the project screw standard).

**Why.** Inverting the *mounting* structure inward (lens still out) keeps the outside clean and the
camera captured; the counterbore keeps the screw head below the surface so nothing snags. The camera
is powered **over the MIPI by the VTX** — there is no separate camera wire.

**Watch out.**
- **MIPI seated at an angle / half-in** → the ribbon is fragile and the contact is finicky; a dark
  or glitchy picture is almost always the MIPI, not the camera. Re-seat gently, straight in.
- **Creasing the ribbon** → don't fold it to make it fit; give it a gentle service loop.
- **Lens proud of the wall** → check the cradle depth; the outer face should sit flush, not stick
  out (the whole point of the inverted mount).

*(Photo lands with the first physical build log — every claim above comes from the executed CAD, not a stock image.)*

---

## Step 5 · XT30 strain relief — lay in, lock, *then* solder behind

*This is the one place a soldering iron touches the power side, and it happens **after** the cable
is mechanically captured, so the solder joint never carries load.*

**Do, in this exact order:**
1. **Lay** the two battery-lead conductors (**Ø 2.8 mm each**, measured) into their **two separate
   channels** on the strain-relief saddle — red in one, black in the other. Each channel closes to a
   **2.6 mm clear width** (**−0.2 mm** on the 2.8 conductor), separated by a **~1.8 mm web**.
2. **Close the bar** over them: **2× M2 DIN 912 cap screws into printed Ø 1.7 mm cores** (undersize
   on purpose — print shrink lets the screw cut its own thread). Snug evenly until the conductors
   are captured.
3. **Only now** solder the **XT30 behind the clamp** (on the far/door side, +X end), with the
   ≥ 10 mm of iron clearance the block leaves toward the door.

**Why.** Two separate channels stop the conductors wandering (one wide channel lets them cross). The
**−0.2 mm** grip captures each conductor mechanically **before** anything is soldered, so a pull on
the battery cable lands in the printed block and the **XT30 joint sits load-free**. The
**base is printed integral to the body** (stronger than a bolt-on back plate, no mounting screws),
and the saddle builds **up/inward** (never down toward the battery) — the XT30 stows up top, so the
geometry agrees with itself.

**Watch out.**
- **Soldered the XT30 first** → you can no longer lay the conductors into the channels; you'd have
  to feed the whole connector through. Wrong order — the mechanical capture must come first.
- **One conductor jumped its channel / both in one groove** → they'll chafe and can short; each gets
  its own channel, red and black kept apart.
- **Conductor squashed flat under the bar** → over-tightened; −0.2 is a grip, ease off.
- **Iron can't reach / melts the block** → respect the ≥ 10 mm clearance toward the door and keep
  the tip on the terminal, not the plastic.

*(Photo lands with the first physical build log — every claim above comes from the executed CAD, not a stock image.)*
**two** of these saddles (left + right at the door end).

---

## Step 6 · Power wiring — Path B quick-build (three Wago 221-412)

*(This step is the **Wago quick-build path**. The **soldered build is the recommended flight
configuration** — same wiring map, every `[joint]` soldered + heat-shrunk, leads cut to their
true run length. Both paths in [`BUILD_GUIDE.md` § 4](BUILD_GUIDE.md#4--wiring--one-map-two-paths)
— reproduced here so the sequence reads in one place.)*

**Do.** Plug the stock **JST-GH 6-pin harness** into the VTX and take **red (+) and black (GND)**;
cap the unused yellow/white/blue with heat-shrink. Then three **Wago 221-412** lever clamps:

```
Battery XT30 ── pigtail (+) ──[Wago]── switch ──[Wago]── VTX red (+)
                pigtail (−) ──[Wago]──────────────────── VTX black (GND)
```

The **+ line uses two Wagos** (through the switch); the **− line uses one**. Strip to the Wago's
window, flip the lever down, done. Thin strand wobbling in the clamp? **Fold the bare end double** —
no ferrule, no crimper. When wiring is confirmed, put a dab of **RTV/hot glue on each lever** against
vibration.

**Why.** No motors, clean supply → **no capacitor, no solder** on the power path. Levers re-open in
seconds for service. The switch **breaks the battery + line directly** (~1.3 A, [CALC] 850 mAh /
~1.3 A).

**Watch out.**
- **Lever not fully closed** → intermittent power, the worst kind of fault in the air. Every lever
  flat-down, give each wire a gentle tug.
- **Balance (JST-XH) plug wandering toward the VTX** → **charging only**, never toward the VTX.
- **Reverse polarity** → the VTX has **no reverse-polarity protection**. See Step 8 — multimeter
  before first power, no exceptions.

---

## Step 7 · Dress the cables through the fixed shelf

**Do.** The divider shelf is **printed into the body** — there is nothing to install. Route the
battery leads **up through the shelf cut-outs** (two large windows at the ±X ends; the +X one is
the XT30/airflow window), lay each cable **into** its opening — laid in, never threaded through a
closed hole. Park the mated XT30 and the Wago bank in the **left-hand zone** of floor 2 (the open
volume beside the camera module).

**Why.** A printed-in shelf removes one part, one alignment step and two screws versus a drop-in
tray, and the interlayer joint is replaced by solid walls. The cut-outs double as the chimney
airflow path. Derivation: [`ENGINEERING/divider.md`](ENGINEERING/divider.md) *(the tray analysis
there documents the earlier drop-in design — superseded by the printed-in shelf).*

**Watch out.**
- **Cable pinched between battery and shelf** → the battery won't slide fully home; route leads
  into the +X window *before* seating the battery.
- **Wagos drifting over the VTX** → keep them in the left-hand zone; the VTX needs its full
  clearance under the lid.

*(Photo lands with the first physical build log — every claim above comes from the executed CAD, not a stock image.)*
---

## Step 8 · First power (bench) — the ritual that saves the VTX

**Do, every time, in order:**
1. **Antenna on BEFORE power — always.** SMA mated (or a **50 Ω dummy load**) *before* the battery
   goes in.
2. **Multimeter on the VTX red/black:** red must read **+11–12.6 V** (3S), red = +, black = −.
3. Battery in → the VTX boots in **pit mode (0 mW)**. Set channel and power from the **ground-station
   (BoxPro) menu**, lowest usable power, watch the heat.

**Why.** Powering a VTX **without an antenna reflects the PA's own power back into it and kills it
instantly** — this is the single most common way these die. The **no reverse-polarity protection**
means one swapped Wago at 12 V ends the VTX; the multimeter is a hard gate.

**Watch out.**
- **The omni is external and visible — look at it.** Antenna flat against the wall, SMA mated,
  T-clamp tight. No antenna on the wall = do not power.
- **Any heat you can't hold a finger on within ~2 min at > 25 mW in the closed case** → power down;
  that's the thermal envelope, not a surprise.

---

## Step 9 · Close the battery door (the TV-remote move)

**Do.** With the battery in its bay (and its **foam preload** in place so it can't fly free), fit
the door: **slide it in along the bay**, then a **gentle end-tilt (≤ 4°)** until the two retaining
noses at the foot drop into their floor pockets, and press the plate flush. Then drive the
**single M2×6 DIN 912 screw through the top tab into its brass insert** — the small tab that sits proud on the wall above
the opening — into its printed core. It works like a TV-remote battery door: slide, tip, seat,
one screw. The tab is also your grip for opening.

**Why.** The slide-then-tilt lets the noses engage without forcing the door square onto them; the
tab screw is the positive lock and threads into the **wall + shelf ledge, never into the bay** —
the battery volume stays completely unclaimed (an earlier interior boss design would have collided
with the swollen pack by up to 2 mm; a permanent geometry gate now proves the bay empty on every
rebuild). The **foam preload is mandatory** — a loose 80 g pack hits ~590 N on a hard stop, the
foam cuts that to ~250 N ([CALC], [`ENGINEERING/divider.md`](ENGINEERING/divider.md)).

**Watch out.**
- **Tilting more than a few degrees / forcing it flat** → you'll shear or miss the noses. Small
  tilt, let them catch, then press.
- **Door springs back before the screw** → a nose isn't engaged or a cable is pinched behind the
  door; back out, clear the cable, retry. Don't drive the screw to pull a mis-seated door closed.
- **Door rattles after the screw** → foam preload missing or too thin; the pack must be captured,
  not free.

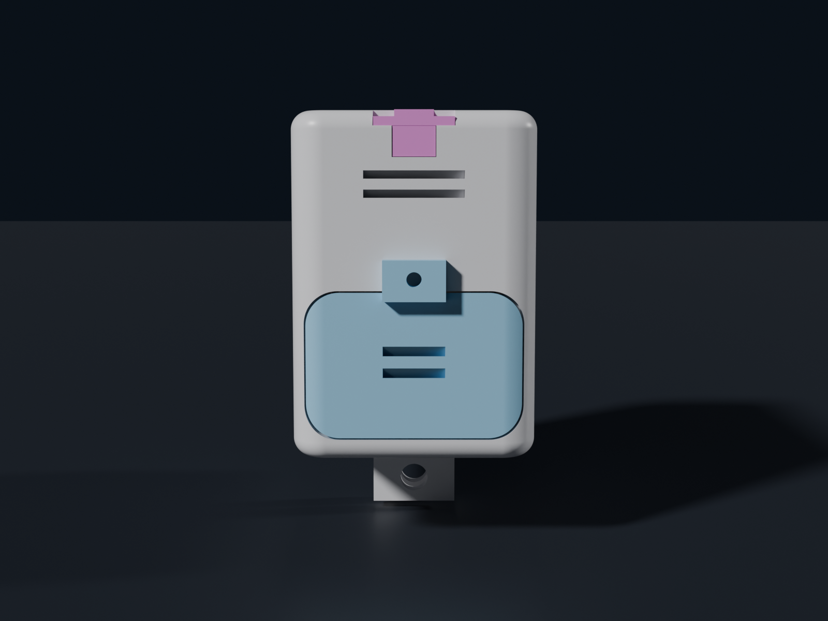
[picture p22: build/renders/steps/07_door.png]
The finished door: flush plate, two mini louvers, top tab with its single M2 — feet and noses work invisibly behind the outer skin


---

## Step 10 · Final walk-around before the case is trusted

- Every **Wago lever flat-down**, glued; give each wire a tug.
- **Multimeter** polarity re-checked at the VTX.
- **Antenna against the wall**, T-clamp nose tight on the coax, SMA snug.
- **Thermal pad** compressed, no air gap.
- **Strain reliefs** (antenna clamp + both XT30 saddles) hold against a firm cable pull — the pull
  lands in the printed block, not on a joint.
- **Battery door** clicked and screwed; **foam preload** present.
- **Roof lid** seated on its rebate (lip dips into the opening, flush on top), 3× M3 snug from above (not crushing the posts); the 12 mm switch pokes through its lid hole.

Then — and only then — go to the empirical protocol: **[`MEASURE.md`](MEASURE.md)** (VNA S11 of the
antenna with its coax clamped, the thermal A/B test, the caliper list). This assembly is
**bench-verified pending**: the shell prints and the parts fit on the reference prototype, but no
step above has a *measured* badge until you run those tests on your own build.

*(Photo lands with the first physical build log — every claim above comes from the executed CAD, not a stock image.)*

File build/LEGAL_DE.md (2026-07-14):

# SkyLive — Legal framework (Germany, 5.8 GHz FPV live stream)

*Condensed English edition of the project's German legal research (`RECHTSRAHMEN`, 2026-07).*

> ⚠️ **This is NOT legal advice.** It is technical project research without legal qualification.
> Labels: **[LAW]** = primary source with citation · **[PRACTICE]** = documented (partly informal)
> regulator practice · **[ASSESSMENT]** = our own reading. Before any operation above 25 mW:
> get written clarification from BNetzA (the German regulator) / DARC. If you rebuild this
> outside Germany, your own jurisdiction's rules apply — check them first.

## 1 · The three ways to operate

| | **(a) SRD general authorization** | **(b) Amateur radio (Class E)** | **(c) PMSE short-term assignment** |
|---|---|---|---|
| Who | anyone, no licence | licence holders only | applicant (event operator) |
| Frequency | 5725–5875 MHz | 5650–5850 MHz (amateur is **secondary**) | assigned by BNetzA (5.8 GHz can be requested, not guaranteed) |
| Power | **25 mW EIRP**, no exceptions | 5 W PEP (since 06/2024) | set in the assignment; > 25 mW possible, 1 W not guaranteed |
| Public-viewing demo | unproblematic | **critical** — see § 2 | unproblematic; explicitly meant for sport events |
| Procedure / cost | none / € 0 | exam + call sign | apply ≥ 15 working days ahead, from ~€ 30 |
| Verdict | **legal today — the standard path for ALL tests** | **fragile** (four open points) | **the robust path for the event demo** |

Sources [LAW]: BNetzA Vfg 91/2025 (SRD) · AFuV Annex 1 as amended 2024 (BGBl. 2024 I Nr. 175) ·
§ 55 TKG + BNetzA short-term-assignment practice.

## 2 · Why 1 W under an amateur licence stays LOCKED (the honest part)

1. **Purpose**: is an FPV video feed amateur radio at all? A documented (informal) BNetzA reply
   from 2013 read model-flight video links narrowly. Our case differs (ATV-like, no control
   link), but the narrow reading exists. [PRACTICE]
2. **"For third parties" / broadcast-like**: § 5 AFuG forbids message transfer for third
   parties; § 16(9) AFuV forbids broadcast-like programming. A live feed onto a public DZ
   screen is one-way entertainment for an unspecified audience — a realistic reading says:
   not permitted. No ruling, no official statement on this exact case. [LAW + ASSESSMENT]
3. **Encryption/obscuring clause § 16(8) AFuV (2024 wording)**: recoverability with generally
   available equipment is the yardstick — any store-bought HDZero receiver recovers the
   picture, and there is no intent to obscure. Probably defused for HDZero; officially
   unresolved. [LAW + ASSESSMENT]
4. **Bandwidth — the hard, often-missed blocker**: AFuV Annex 1, usage rule 9 caps occupied
   bandwidth at **10 MHz, or 20 MHz for television transmissions**. HDZero occupies **27 MHz**
   in standard mode and **17 MHz** in narrow mode (540p60). **Standard HDZero exceeds even the
   20 MHz TV cap** — only narrow mode could fit, and only if the feed counts as television. [LAW]

**[ASSESSMENT]** Power is covered (1 W ≤ 5 W PEP) — but points 1–2 question whether the
transmission is amateur radio at all, and point 4 blocks the standard HDZero mode technically.
Class E is an option after written clarification, not a foundation.

## 3 · The project's operating doctrine

| phase | path | configuration |
|---|---|---|
| **All testing** (bench, range, jump trials) | SRD general authorization | VTX locked to **25 mW**, 5725–5875 MHz. Legal immediately, no application. Key question to answer empirically: does 25 mW + aimed ground antenna close 4 km line-of-sight? |
| **Event demo** | **PMSE short-term assignment** | apply to BNetzA ≥ 15 working days before the event: place/date, 5.8 GHz video link, TX power, antenna characteristics, duration. From ~€ 30. |
| **1 W amateur operation** | **locked until clarified** | only after written BNetzA/DARC answers on purpose/third-parties/broadcast **and** a bandwidth solution (narrow mode 17 MHz or a cleared reading of rule 9). |

## 4 · SAR and harmonics (any path above 25 mW)

- **SAR — 1 W next to a head:** the sender sits on the helmet, centimetres from the skull.
  Reference: ICNIRP/EU limit 2 W/kg (local, 10 g average). At 25 mW uncritical [ASSESSMENT];
  at 1 W the antenna-to-head distance is the decisive quantity. The side-wall antenna
  placement (radiating away from the head) helps but **replaces no assessment** — a SAR
  evaluation is a hard gate before real 1 W operation or giving the device to anyone else.
  No measurement exists — not overclaimed.
- **Harmonics @ 1 W:** required suppression ≥ 50 dBc → each harmonic ≤ −20 dBm absolute [LAW:
  AFuV Annex 1 B; Vfg 33/2007]. 2nd harmonic = 11.6 GHz, 3rd = 17.4 GHz → proof needs an
  ≥ 18 GHz analyzer (a tinySA Ultra tops out at 6 GHz). Practical path: band-pass filter in
  line → fundamental checked locally → harmonics spot-checked in a properly equipped lab.

## 5 · Disclaimer

Anyone reproducing this work is responsible for their own regulatory compliance. This project
publishes its legal homework so you can do yours — it does not do it for you.

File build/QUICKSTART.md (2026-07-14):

# Build a SkyLive sender — the whole thing on one page

*Every number below comes from the executed CAD or a caliper. Deep dives are linked at each step —
this page alone is enough to build one. **Wiring: soldered is the recommended flight build**
(cut every lead to its real run length — lighter, tighter, tougher); the Wago path below is the
zero-solder quick-build for your first assembly.*

## 1 · Buy (≈ €160 for the sender, EU prices 2026-07)

| # | part | ≈ € |
|---|---|---|
| 1 | HDZero Freestyle V2 VTX kit (incl. Nano90 camera + MIPI + JST-GH harness) | 90 |
| 2 | Tattu R-Line 3S 850 mAh XT30 (or 3S 300 HV for the Mini) | 12 |
| 3 | 12 mm latching push-button (850 only — the Mini has no switch by design) | 5 |
| 4 | 3× Wago 221-412 · XT30 female pigtail | 8 |
| 5 | RHCP 5.8 GHz omni (U.FL→SMA semi-rigid pigtail, Ø3.1 jacket) | 18 |
| 6 | Filament: PETG (fit prints) / ASA (final) — **never PLA** | 25/kg |
| 7 | Brass inserts: 3× M3 (Ø5×6) + 1× M2 (Ø3.2×3) | 3 |
| 8 | DIN 912 cap screws: 3× M3×8 · 8× M2×8 · 1× M2×6 · 2× M2 (camera) | 4 |
| 9 | 1.5 mm silicone thermal pad · 2 mm EVA foam · 50 Ω SMA dummy load | 14 |

Full alternatives table (other VTX/cameras/batteries with exact dimensions): [`BOM.md`](BOM.md)

## 2 · Print (4 files + 2 small parts twice)

`01_body` **lying on its back wall** (GoPro teeth horizontal = strong) · `02_lid`, `03_door`,
`04_latch ×2`, `05_T-piece ×2` flat. PETG 0.2 mm, 4 perimeters, 40 % gyroid, cooling ≤ 50 %,
paint-on supports only where marked. Full sheet: [`PRINT_DE.md`](PRINT_DE.md) (German) ·
dimensions: all three sizes are listed in the root README (measured from the executed CAD)

## 3 · Inserts first (empty shell, iron at 250–270 °C)

3× M3 into the roof posts from above · 1× M2 into the Ø2.8 bore above the battery opening
(horizontal, from outside — the door tab hides it). Sink 0.3 mm sub-flush. [Step 1 →](ASSEMBLY_STEPS.md)

## 4 · Antenna clamp (the screws ARE the clamp)

Drop the Ø3.1 coax **from above, all the way down** into the round Ø3.2 seat on either short
side — it goes in easily, the seat has clearance by design. The cable runs **horizontally
through the wall**, the omni sits right against it outside, axis through the wall. Slide the
T-piece down: its **R1.55 nose lands on the cable**, then **2× M2×8 (heads up) pull the nose
0.4 mm onto it — that's the clamp**. Nothing to drill or notch; both T-pieces identical, pick
either side. Finish with a firm pull test on the antenna. [Step 2 →](ASSEMBLY_STEPS.md)

## 5 · Electronics — solder it (recommended) or Wago it (quick)

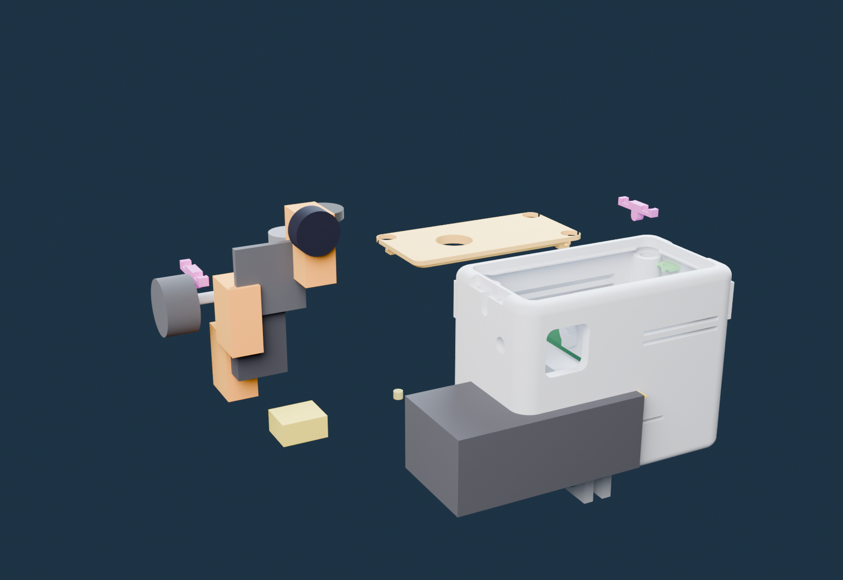
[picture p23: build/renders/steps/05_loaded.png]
Every component mid-flight into its bay — radio, camera, battery, switch, Wagos, XT30, antenna (stylised to their measured envelopes). Watch it animated in the 3D Lab.

*Where everything lives — [watch them fly in, animated](https://schoentom.github.io/skylive/viewer.html) (▶ Fly-in tab).*

VTX flat on its thermal pad against the wall · camera into its corner cradle (2× M2, the left one
comes through the outer wall) · battery leads into the saddle grooves, latch them (2× M2 each),
**then** plug XT30 · switch into the lid (850) · power joins: **solder + heat-shrink, leads trimmed to their true run** (recommended) — or 3× Wago 221-412 for the solder-free first build.
Wiring map + the three hardware killers (never power without antenna/dummy · multimeter polarity
check · U.FL seats once): [`BUILD_GUIDE.md`](BUILD_GUIDE.md)

## 6 · First power — on the bench

Dummy load on, 25 mW only, multimeter says +11–12.6 V on red. Picture on the goggles/monitor?
Then: foam pad in, battery in, door: slide → tip ≤ 4° → noses catch → 1× M2×6 into the brass
insert. Done. Full ritual + failure table: [Steps 8–10 →](ASSEMBLY_STEPS.md)

---

**Honesty ledger:** everything geometric here is gate-verified CAD; clamp holding force, insert
strength and RF tuning carry `MEASURE_ME` until the physical build log lands.
[What the gates caught →](WHAT_THE_GATES_CAUGHT.md)

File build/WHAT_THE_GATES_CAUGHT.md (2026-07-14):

# What the gates caught

*Every part in this repo was built by parametric CAD code with **assertion gates** — boolean
collision checks, wall-thickness sweeps, screwdriver-path probes — that run on every rebuild and
**refuse to export** if anything intersects. This file is the honest logbook of what those gates
caught before a single gram of filament was wasted. Most hardware repos show you the result.
This one shows you the saves.*

---

## The lid that could never be screwed — **687 mm³**

The first lid design anchored its four M3 insert bosses on the long side wall, reaching 10.5 mm
into the interior. A neutral audit placed the *nominal* VTX envelope (29.2 × 30 × 18.6 mm) against
every interior feature — and found the bosses buried **687 mm³ deep inside the radio**. Not a
tolerance issue: with the VTX needing 30 of the 33.5 mm interior width, *any* boss deeper than
1.75 mm on that wall collides, always. The fix wasn't a smaller boss — it was moving the lid to
the **roof**, where three corner posts live in space no component ever claims.

> Lesson: check envelopes against *nominal* positions, never against the already-carved body.
> A gate that "passes" because the conflict was carved away is a lie with green text.

## The door that could not swing — **a geometric proof**

The battery door was designed to hinge in like a TV-remote lid. The swing simulation (door rotated
about its nose line in 2° steps, intersected with the body) showed **60–180 mm³ of collision at
every angle past 1°** — and stayed above 60 mm³ even with the *entire top half of the door
deleted*. The culprit: the R6 interior corner fillet, which curves the cavity wall into the path
of the door's tongue flanks. That's not a bug to patch; it's a proof that a flush four-sided plug
door cannot rotate into a filleted cavity. The door now **slides in straight and tips ≤ 4°** at
the end to hook its noses (0.00 / 0.07 mm³ at 2°/4° — measured, gated) — which is exactly how a
real TV-remote door seats, so nothing of value was lost. The full sweep is still logged on every
build, honestly, above the assert that checks what is actually achievable.

## The vent that opened into the camera — **24.65 mm³**

When the camera moved fully outboard against the front wall (so its left screw could pass through
the *outside* of the case — one countersink, zero internal structure), the upper front vents
suddenly opened straight into the camera's back. The collision gate flagged 24.65 mm³ on the next
build. The vents weren't nudged — they were **deleted**, because the honest reading was that the
zone is simply occupied now. The lower vents (battery floor) stayed.

## The strain-relief boss that swallowed an insert hole — **a blocked drill**

The antenna strain-relief's threaded boss and a lid corner post both wanted the same patch of the
front wall. The gate that failed wasn't a collision check — it was a **0.4 mm air-cube probe**
placed inside the insert bore, asserting the hole is actually open. It found solid brass-to-be:
the strain relief's boss had quietly filled the corner post's drilling. Two constants moved
(the strain relief slid to wall-center, its boss shortened 0.5 mm clear of the camera), and the
probe breathed again.

## The screw path with a burr in it — **2.5 mm³**

A Ø3 mm virtual screwdriver, driven down each lid screw axis, clipped 2.5 mm³ of rebate-shoulder
material hanging over the corner posts. Invisible in any render; a real obstruction for a real
hex key. The posts now carry a Ø4 clearance bore through the shoulder — which the M3 shaft needed
anyway.

## The door boss that would have blocked the battery — **caught by a question**

The battery door was held by an M2 screw driven into an interior boss — a 7 × 7 mm block
reaching from the rear wall into the battery bay. It passed every *existing* gate, because no
gate ever placed the **battery's nominal envelope** against it: the 60 mm pack plus 1 mm of
swell ends at X 28.5, and the boss began at X 26.5 — **up to 2 mm of guaranteed interference**,
invisible in renders, waiting for the first real battery. The catch came from asking the
audit question out loud ("does the pack even fit past that thread?") and then encoding it:
the boss is gone, the door now closes with a flat top tab screwed into the wall + shelf ledge
(zero interior claim), and a new `[akku-frei]` gate asserts the ex-boss zone intersects
**0.00 mm³** of body on every rebuild — so this class of bug can't come back quietly.

> Lesson: a gate only protects what it measures. Every envelope that shares space with a
> printed feature needs its own nominal-collision assert — "nobody complained yet" is not one.

---

## The strain relief we read backwards — **overturned by a neutral review**

For days this design carried a confident claim: the antenna coax is held by a **2.9 mm
press-fit slot** ("−0.2 mm interference, the slot grips the jacket") and the T-piece is merely
a lid. It sounded right, it gate-checked green — and it was a misreading of the reference
build. When the builder pushed back ("the cable should go all the way down and be *fully*
clamped — pressed by the two screws"), the claim was handed to a **neutral reviewing agent**
with photographs and the reference STEP files, with instructions to explain the mechanism from
scratch. The measurements said the opposite of the claim: the reference seat is **Ø 3.2 with
clearance** on a Ø 3.1 cable, and the T-piece's stem ends in a **convex nose of R 1.55 —
exactly the cable radius**. The slot guides; the seat supports; **the two vertical M2 screws
create the clamping force** by pulling the nose 0.4 mm onto the cable.

Both senders were rebuilt to the real mechanism, and the old gate ("T-piece must never touch
the cable") was replaced by its inverse: a **clamp gate** that lays a nominal Ø 3.1 coax in the
seat and asserts the seated T-piece interferes with it by a *defined* amount — 1.15 mm³, the
0.4 mm press — on every rebuild.

> Lesson: a gate can only defend the design intent you encoded. If the intent itself is a
> misreading, green gates just make the mistake reproducible. When the person holding the
> physical part says "that's not how this works" — measure again, from scratch, without your
> own assumptions in the prompt.

---

## The counterbore that swallowed the screw head — **caught by looking at the part**

The roof lid is 3.0 mm thick. Its three M3 counterbores were speced at Ø 6.1 × **3.4 deep** —
head height 3.0 plus 0.4 to sit sub-flush. Nobody ever held that 3.4 against the 3.0 the lid
actually has: the counterbore went **clean through**, turning each screw hole into a Ø 6.1
through-bore. The Ø 5.5 cap head would have dropped straight through the lid and clamped
nothing — a lid held by friction and hope. Every existing gate passed, because every existing
gate checked shape validity and collisions, not *function*. The catch came from looking at the
printed-parts preview and asking the obvious question: "does that head actually bear on
anything?"

The final fix came from the reference build's own lid: its STEP file measures **4.5 mm thick**
with a **Ø 6.5 × 3.4 counterbore** — a 1.1 mm floor, head sunk 0.4 sub-flush. This lid gets
there with **local Ø 10 × 1.5 pads on its underside** (4.5 mm exactly where the screws live,
3.0 everywhere else), the bosses shortened to make room, and the screws moved 1 mm diagonally
inboard so the sunken head sits entirely inside the rebate's corner radius — each constraint
found and enforced by the rebuilt `[deckel-kopf]` gate (floor bears, head is sub-flush, head
touches no body material).

> Lesson: the drawing convention ("head height + 0.4") is not a design check. Every
> counterbore depth needs to be asserted against the *local* thickness it lives in.

---

## The tab a neighbor spotted — **15 mm²**

The battery door closes with a classic proud tab: a flat tongue over the wall, one M2 into a
brass insert. Every gate was green — form closure 0.000 mm³, zero overhang past the tab, swing
sweep clean. Then, at the lab's slicing station, someone leaned over from the next PC and said
the joint between the door and that tab *"looks weak."* He was right, and measurably so: the
tab bonded to the door's outer face over a strip of just **10 × 1.5 mm — 15 mm²** — and the
tab doubles as the grip, so that little patch gets **peel-loaded** every time someone levers
the open door by it. Peel on a small printed bond line is the classic crack starter, and no
gate had ever *measured* the bond, because the intent "tab attaches here" was encoded as a
boolean union, not as an area worth asserting.

The fix cost nothing anywhere else: the tab grew from 10 to 12 mm wide (+20 % at the critical
parting-line section) and its bonding apron was extended from 1.5 to 6 mm down the door face —
**72 mm² of lap joint instead of 15 of peel line** (54 mm² on the mini, whose door louvers sit
higher). The body, lid, latches and strain-relief tees are byte-identical to before; only the
door reprints.

> Lesson: gates only defend what you thought to measure — and a fresh pair of eyes is a gate
> you can't write. This project is open source on purpose; critique from the next desk over
> is part of the toolchain. (Whether the joint *holds* is still a pull test, not a boolean.)

---

## The review that upgraded the gate itself — and found three real bugs

A colleague printed the sender, opened the STEPs in SolidWorks, and sent back two videos of
findings. Chasing them taught the toolchain more than any single fix:

- **"Infinitely thin edges everywhere the radius runs out"** — the mesh gate confirmed
  sub-0.1 mm readings all over the body… and then section renders showed every one of them is
  a *tangency cusp* where a fillet feathers into a plane. The printed part in hand proves the
  slicer just merges them. The naive gate was crying wolf.
- So the gate learned to *classify*, not just measure: a thin cluster is only a FAIL if it is
  **a surface, not a curve** (PCA width) **and a plateau, not a ramp** (thickness IQR).
  Calibration anchors: a synthetic 0.4 mm membrane must FAIL, an acute wedge must PASS,
  the louver blades (0.72 mm by design, printed successfully) must WARN — not block.
- The upgraded gate immediately caught **three real design bugs** the old one was blind to:
  a 0.5 mm counterbore floor in the flush strain-relief tee (now 1.0 mm), an XT30 clamp bar
  that was sub-millimetre over its cable grooves in *every* size (now 1.7 mm of floor), and
  groove positions on the mid-size body that had never been rescaled after the case got
  narrower — one groove was quietly eating 0.8 mm into the wall.
- The one part that actually **broke** in the field — a GoPro fork finger — already had its
  root fillet. The real culprit is layer orientation on a one-piece body: the fingers print
  vertically, layers across the load. A bigger radius is measured-fit-gated; until then the
  doctrine is a brim and no prying.

> Lesson: a printability gate is a hypothesis about what "unprintable" means. A real print,
> a real break, and a skeptical reviewer are the experiments that falsify it. Version 2 of
> the gate now ships in `build/cad/printability_gate.py` and runs as a hard export gate in
> all three model scripts.

---

## Why this matters

None of these were visible in a render. All of them would have cost a print, an evening, and a
little trust in the design. The point of gate-driven CAD isn't that the code is clever — it's
that **the model refuses to lie to you**. When this repo says the parts fit, that claim has been
executed, not eyeballed.

*(And where the gates can't reach — insert melt strength, snap cycles, RF detuning — the docs say
`MEASURE_ME` and mean it. A CAD boolean is not a test.)*

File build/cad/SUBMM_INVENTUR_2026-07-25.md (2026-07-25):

# Sub-mm-Inventur — Zwischengröße (`mid_sender.py`), 2026-07-25

Ingenieur-Leitlinie: „Alles unter 1 mm muss größer oder stabiler — zu filigran für den Drucker."
Regel dieser Inventur: **Wände/Stege** < 1 mm sind Kandidaten. **Spalte/Toleranzen/Quetschmaße**
sind ABSICHTLICH klein und tabu — sie zu vergrößern zerstört Passung oder Klemmung.
Backstop auf Mesh-Ebene: das Printability-Gate v2 failt bei jedem Export hart auf
flächige Dünnwand-Plateaus < 0,8 mm (aktuell: 6/6 PASS).

## Heute durch die Fixes BESEITIGT (waren die echten Sünder)

| Feature | war | Status |
|---|---|---|
| Tür-Finger t=1,2 quer zur Schicht + 90°-Haken 1,0 | brach beim Absupporten | **F3: ersatzlos entfernt** |
| XT30-M2-Kern-TRÄGER = freier 6,6er-Finger | „Löcher praktisch nicht vorhanden" | **F2: Kerne in Vollmaterial-Brücke** — Korrektur (Review): im Rinnen-Tiefenband (oberste 1,3) schneidet der Kern wie in v1 beidseitig 0,15 in die Rinnenflanken; darunter voll ummantelt. Der eigentliche Fix ist der massive Träger. |
| XT30-Finger-Sättel 6,6 breit, frei zu Mitte+Rand | Support-fragil | **F2: durchgehende Brücke** |
| Kamera-Flanke nur an Schichtnaht der Wand | riss beim Absupporten | **F1: Fuß auf Shelf** |
| Omni-Kappen-Piloten Ø1,7 horizontal in 3er-Wand | Seitenhalterung | **F4: ersatzlos entfernt** |

## Bleibt — mit Begründung (Toms Entscheidung, Zeile für Zeile)

| # | Feature | Maß | Klasse | Empfehlung |
|---|---|---|---|---|
| 1 | Vent-Lamellen-Steg (senkrecht, 45°-Projektion) | **0,72** (VENT_W 1,4 · Pitch 3,0) | bewusstes Feinfeature | **Lassen** — am 850er-Druck bewiesen (druckt als 1–2-Perimeter-Band). Falls Tom mehr Fleisch will: Pitch 3,0→3,4 ⇒ Steg 1,0, Kosten: ~12 % weniger Luftquerschnitt. |
| 2 | ZE-Insert-Restwand nach außen | ~1,5–1,6 | grenzwertig, dokumentiert | Lassen (Druckhinweis „vorsichtig einschmelzen" im README existiert). |
| 3 | Tür-Pilot M2 selbstschneidend | Ø1,6 Kern | Funktionsmaß | Lassen (Schraube braucht Biss). |
| 4 | XT30-M2-Kerne | Ø1,7 Kern | Funktionsmaß | Lassen — seit F2 voll ummantelt. |
| 5 | GoPro-Zinken-Wurzel-Fillet | R0,8 | Feinfeature | Lassen (Tom: „Zinken sind perfekt"; mehr Radius erst nach Fit-Messung, TOM_PENDING #5). |
| 6 | XT30-Brücken-Rinnenboden (Nachtrag Review) | **0,7** (Brücke 2,0 − Rinne 1,3) | tragende Bogen-Geometrie unter Klemmlast | Beobachten am Fit-Print; Bogen (kein Plateau) → Printability-Gate grün. Bei Bruch: XT30_SAD_Z-Band um 0,5 höher ziehen. |

## Tabu-Liste (klein = Absicht, NIE „aufdicken")

| Maß | Wert | Funktion |
|---|---|---|
| TOL_SLIDE | 0,3/Seite | Tür-Gleitspiel — größer = Klappern, kleiner = klemmt |
| Kabel-Quetsch | 0,2 (Licht 2,6 auf Ader 2,8) | DIE Klemmwirkung der Zugentlastung |
| AZE_CLR | 0,1/Seite | T-Stück-Passung |
| Diverse 0,1/0,2/0,3-Offsets | — | Montage-/Schwenkluft, Blind-Schultern |

*Konstanten-Ebene vollständig geprüft; Mesh-Ebene übernimmt das Gate (hart < 0,8). CAD ≠ Drucktest.*

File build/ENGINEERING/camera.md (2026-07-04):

# The camera — a Nano90 cradled behind a flush lens window

*Engineering note for the sender's camera integration. Labels: sourced (manufacturer / STEP
file), **[CALC]** = geometric model, `MEASURE_ME` = must be calipered on the real part.
**A watertight CAD boolean is not an empirical fit test** — a printed coupon check of the lens
window and cradle is mandatory before the retention is believed. Geometry lands in the case
CAD: see [`../cad/README.md`](../cad/README.md).*

## 1 · The part

**HDZero Nano90** (official STEP, calipered against it): board **14 × 18 × 18.5 mm**, lens
barrel **Ø12 mm protruding ~13.3 mm** from the board face. It is powered and read out over a
single **20-pin MIPI ribbon** from the Freestyle V2 VTX — there is **no separate camera power
and no BEC**. The ribbon is fragile and short; it wants the camera close to the VTX and its
service loop protected, not stretched.

The camera carries a **native side-wall mount: 2 × M2, Ø2.0 mm clearance, 14 mm apart**
(STEP-measured). We deliberately do **not** use it — see § 3.

## 2 · The lens window (flush, snag-safe)

The lens looks out through the long front wall. The opening is a **13.5 × 13.5 mm rounded
square, corner R2.5**, cut through the 3.0 mm wall so the Ø12 barrel clears with ~0.75 mm all
round [CALC]. Two rules drive the detail:

- **Recessed, never proud.** The window face sits **0.5 mm inside** the outer wall, with a
  **1.2 mm × 45° chamfer** breaking every edge. Nothing protrudes into the airstream or a
  riser's path — the whole sender's job is to not snag on a helmet, a canopy line, or a jump
  partner. A protruding lens bezel is exactly the line-catch we design out.
- **No radome over the glass.** The window is left open. (For reference: a thin PETG cover
  would cost only **≈0.15 dB** optically-negligible — but this is *video*, not RF, and an
  extra optical surface fogs and scratches, so the lens stays exposed and the barrel itself
  seals the hole.)

## 3 · Retention — why a cradle, not screws

The obvious move is the camera's own 2 × M2 side holes. On this wall it does not survive the
geometry: threading M2 bosses beside a 13.5 mm window in a 3.0 mm wall leaves a **rail only
~2.1 mm thick that would break through into the window** [CALC]. Driving screws there buys a
weaker wall, not a stronger mount.

So the camera is **cradled**, captured on all six sides by printed structure instead of
fasteners:

- **−Y (forward):** the window shoulder. The 18 mm board cannot pass the 13.5 mm window — it
  seats against the shoulder, positively locating the lens.
- **±X (sides):** two printed rails hug the board width.
- **+Y (rear):** two **0.3 mm snap lips** — a light catch, enough to hold the board back
  against the shoulder during handling, not a structural load path.
- **±Z (top/bottom):** the closed lid above and the VTX body below trap it once assembled.

Net: zero fasteners at the camera, no thin threaded rail, and the board is fully constrained
the moment the lid closes. Honest limit — this is a **fit-prototype retention**. For a final
build the snap lips or a retention lip may want tuning, or a dab of RTV on the board edge;
that is a `MEASURE_ME` on the printed part, not a CAD claim.

## 4 · Placement (and what still needs measuring)

- Camera on the **long front wall**, lens on the optical axis, VTX directly behind so the MIPI
  ribbon stays short and its service loop sits in the divider window.
- `MEASURE_ME`: real board thickness tolerance and the lens-barrel seat depth — these set the
  shoulder recess and the snap-lip reach. The 13.3 mm protrusion is from the STEP; confirm on
  the physical camera before locking the wall stack-up.
- `MEASURE_ME`: MIPI ribbon free length and minimum bend radius — drives how far the camera
  can sit from the VTX without stressing the connector.

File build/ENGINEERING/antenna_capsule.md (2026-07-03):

# The antenna capsule — a donut omni captured in the wall

*Condensed English edition of the project's German spec (`OMNI_CAPTIVE_SPEC`, 2026-07-02).
Labels: sourced (manufacturer/datasheet), **[CALC]** = calculated model, `MEASURE_ME` = must be
calipered. **Nothing here is an empirical RF test — VNA verification of the built capsule is
mandatory before any RF value is believed.** Geometry lands in the case CAD: `TBD-CAD-M6`.*

## 1 · The part and the doctrine

**Lumenier AXII 2, RHCP, SMA** (manufacturer page): 2.2 dBic max, SWR ≤ 1.5, **bandwidth
5.3–6.2 GHz** (the 900 MHz reserve that makes encapsulation viable), 73 × 17.5 mm, 7.8 g,
45 mm semi-rigid RG402 cable that is *meant* to be formed once ("90 degrees or more").

**Orientation doctrine:** the puck lies with its axis **across the body (horizontal)** → the
donut pattern fires **down + up**, nulls point out to the sides. The ground station is below
you; laying the antenna re-aims the fixed +2.2 dBic peak at it instead of at the horizon —
worth **~15–18 dB at 4 km over standing it upright** ([CALC], see [`../rf/README.md`](../rf/README.md)).
Better aiming, not more power.

## 2 · Why fully captured (the wind-load math, honestly)

Free-standing like on a quad (puck + 45 mm cable in the wind) [all CALC]:

- Belly, 55 m/s: ~0.9 N on the puck → ~25 MPa bending at the cable root — **survives** (the
  static worry is quantitatively unfounded).
- Head-down/speed, 75 m/s: ~47 MPa vs annealed copper yield 33–70 MPa — **borderline to
  plastic**, and the *real* killers are dynamic: vortex shedding at ~630 Hz fatiguing the SMA
  crimp, riser slap at deployment (not seriously calculable, certainly ≫ 2 N), and snag safety.
- A half-exposed "window" buys nothing: 1.5 mm PETG is RF-transparent, so exposing the puck
  saves ~0 dB and adds a line-catch surface.

**→ 100 % encapsulated, 0 mm free.** Wind load goes into the printed wall structure
(< 0.1 MPa); the cable sees nothing; there is no snag feature and no way to rip the antenna off.

## 3 · The capsule ("nose") design

- Side wall of floor 2, **opposite the thermal-pad wall**, top band: the element ends up
  ≥ ~45 mm off the head centreline — exactly the side-mount offset the RF model credits with
  +4…+5 dB of body-edge relief. Down-lobe clears wall, divider and battery.
- Ø 19 wall opening (puck 17.5 + clearance — an opening, not a thinned wall) + printed cap:
  root zone 3.0 mm, **element band 1.5 mm radome, cylindrical 360°** (the donut radiates
  radially all round), solid 3.0 dome on the pattern-null axis. 2× M3 (nylon preferred) into
  heat-sets.
- The puck is touched only at its two **axis ends** (TPU tip pad + TPU root ring) — the axis is
  the pattern null, so contact there detunes least ("grip at the nulls, air at the lobes" —
  rule of thumb, VNA decides). Preloaded, nothing rattles.
- **Radial air gap 2.5 mm** puck↔radome. Honest label: design decision/rule of thumb, no sourced
  limit exists; the classical λ/10 rule would say 5.2 mm. Defensible because of the antenna's
  900 MHz bandwidth and because its own polycarbonate radome already sits directly on the
  element. **Mandatory verification: VNA S11 of the antenna inside the finished capsule**
  (5.65/5.8/5.95 GHz markers, SWR ≤ 2 in band; instrument must reach 5.8 GHz).
- Cable route: **exactly one 90° bend, R 8 mm** (datasheet minimum 6.35 repeated), formed once
  on a printed jig, ending at an internal SMA jack on a printed rib. The wall-bulkhead topology
  was evaluated and **rejected**: with a captured puck it is geometrically impossible (the whole
  73 mm chain would stand proud) and an external joint is just a lever/corrosion point.
- Swap procedure: open lid → undo SMA (8 mm wrench) → unscrew cap (2× M3) → pull the antenna
  **outward** through its Ø 19 opening. No soldering, the U.FL is never touched.
- Metal keep-out ≥ 13 mm (λ/4 rule of thumb) around the element zone — same value the vent
  layout respects.

## 4 · "Never transmit without an antenna" — solved structurally

1. The antenna is form-locked in the capsule — it cannot vibrate loose, be forgotten, or be
   pulled off; the 90° bend + TPU clamping block the only loosening motion.
2. **Witness hole Ø 2.5 in the dome centre** (on the pattern null — RF-irrelevant): the TPU tip
   pad behind it is **signal orange**. Orange dot = antenna inside; dark hole = EMPTY.
3. Checklist line stays: "Orange dot visible? Only then power."
4. Deliberately **not** built: electronic antenna detection — extra electronics contradict the
   four-part doctrine, and the VTX documents no VSWR protection to rely on.

## 5 · Version B — the down patch (unchanged variant)

The TBS 5G8 patch (RHCP, **RP-SMA** on this project's unit — match your pigtail!) lives in the
**bottom shell**: a 15 mm hollow cap with a 1.5 mm radome floor, radiating down through it,
with its own weep hole at the cavity edge. Best for belly flying with the DZ below/ahead;
swings off-target in head-down — that's the donut's case.

## 6 · Open verifications (honest list)

Caliper: puck head length, SMA body, cable OD (`MEASURE_ME`) → final sink/protrusion numbers.
VNA S11 in the capsule · ground-level RSSI walk-around capsule vs free antenna (expected loss
~0–2 dB, **unmeasured**) · glove pull test + 1.5 m drop of the printed nose · steel-vs-nylon
cap screws A/B on the VNA if steel is used.

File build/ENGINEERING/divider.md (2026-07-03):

# Structure — the divider tray (floor between battery and radio)

*Condensed English edition of the project's German derivation (`DIVIDER_STRUCTURE_SPEC`,
2026-07-02). Everything here is **beam/strip estimation — no FEM, no physical test**; the
1.5 m drop test in [`../MEASURE.md`](../MEASURE.md) is the gate. Sourced values (opening-shock
literature, printed-PETG datasheet, connector datasheets) are cited in the original.*

## 1 · What the divider actually carries

- **Parachute opening shock:** literature puts sport ram-air openings at ~2–5 g, hard openings
  4–6 g (median peaks 4.0–5.1 g in a measured study) → design value **10 g quasi-static**
  (≈ 2× reserve). The 80 g battery then pushes ~8 N — **downward into the bottom shell**, not
  into the divider. Opening shock is negligible for the divider.
- **The sizing case is a 1.5–2 m handling drop onto concrete, case upside down:** the battery
  slams into the divider. With a rigid stop that's ~750 g (~590 N — unacceptable); with **≥ 5 mm
  of foam preload/stopping distance** it drops to ~300 g → **design load 250 N**, both directions.
  **Rule: the battery must NEVER fly free** — foam preload between battery and divider is mandatory.
- **Helmet-mount loads never pass through the divider.** They run GoPro fingers → bottom shell →
  4 corner screws → the four 3 mm walls as a closed tube. The divider is a **bulkhead/frame**:
  only its perimeter attachment is structural (like aircraft frames with big lightening holes) —
  the centre field is expendable.

## 2 · The material truth that drives everything

Printed PETG (manufacturer TDS): tensile **47 MPa in-plane (XY)** but **interlayer adhesion only
18 ± 4 MPa** — 38 %. Whether the divider survives is decided by **print orientation first**,
cutout geometry second.

An integral horizontal divider in an upright-printed case would (1) print as an unsupported
bridge over the whole battery bay, (2) put plate bending exactly onto the weak interlayer
direction, (3) make stiffening ribs unprintable overhangs.

**→ The divider is a SEPARATE, FLAT-PRINTED DROP-IN TRAY:** bending runs in the strong XY plane,
ribs print as vertical walls, all windows/slots are support-free, and cables get **laid in
instead of threaded** — no connector ever passes a closed hole. It rests on 3 × 3 mm ledges
printed onto the walls (additive — the sacrosanct 3.0 mm wall is never grooved), is keyed
around the corner posts, and is held down by 2 diagonal M3 screws.

## 3 · Cutout doctrine (how much you may remove)

- **Perimeter band 6 mm: always solid** — it *is* the bulkhead function.
  Max. 3 defined feed-through breaks, each ≤ 14 mm, locally doubled.
- **Boss/corner zones stay** (Ø ≥ 12 mm solid around every screw/locating point).
- **Centre field: up to 50 % may be cut out**, if remaining webs are ≥ 4 mm (≥ 4 closed slicer
  perimeter loops), webs are triangulated or tied to the ribs, and the **two longitudinal ribs
  (2.4 × 6 mm, on top)** are present. With ribs, the 250 N drop load carries with a safety
  factor ≈ 1.7 in the strong direction — without ribs the plate is marginal-to-failing. [estimate]

## 4 · Feed-through catalogue (all support-free, all sized from datasheets or measured parts)

| what crosses | opening | why this size |
|---|---|---|
| Battery lead with **XT30** | window **14 × 9 mm** or open edge slot | mated XT30 face ≈ 11 × 6 measured + clearance; the old Ø 6.5 hole fit **no** connector — confirmed bug |
| Balance **JST-XH-4** | window 14 × 8.5 mm | 12.3 × 7.5 datasheet + clearance |
| **U.FL→SMA pigtail** (Ø 1.8) | 3 × 3 mm edge notch | aligns with the wall channel |
| Switch leads | round Ø 8.0 mm | standard grommet size; grommet groove = the 3 mm panel |
| MIPI ribbon | **crosses nothing** — camera and VTX both live upstairs | width is published nowhere → `MEASURE_ME` if ever needed |

Edges of all openings rounded r ≥ 1.5 both sides (cable protection without a grommet);
every slot gets a printed zip-tie anchor next to it (strain relief).

## 5 · What was honestly deleted

A spare-antenna pocket in the divider was **calculated and rejected**: the 73 mm omni doesn't
fit any diagonal of the tray field (~60 mm). Pre-bending the spare's semi-rigid cable to force
it in would damage the spare. The spare antenna travels in the ground-station box instead.

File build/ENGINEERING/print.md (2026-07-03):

# Print & form factor — the factor register

*Condensed English edition of the project's German register (`PRINT_FACTOR_REGISTER`,
2026-07-02): every decision that turns CAD into a part that survives a helmet at 200 km/h.
Labels in the original: measured / datasheet / FDM practice / design decision / **coupon**
(= must be calibrated by test print before the full case). Case files: `TBD-CAD-M6`.*

## 1 · Form (GoPro aesthetics without lying about it)

- Form model: GoPro Hero proportions (official 71.8 × 50.8 × 33.6 mm as *reference only*);
  all radii are design decisions, not measured GoPro values.
- Vertical corner radii R 9 outside — **inner radius MUST be R 6 (= R9 − wall)**, otherwise the
  corner wall silently thins to ~0.5 mm exactly where the case hits concrete.
- Lid seam as a deliberate shadow gap (0.8–1 mm chamfer both sides) — a 0.1 mm print offset
  reads as design, not defect; no snag lip.
- Raised conical bezel ring around the lens; camera set so the lens tip stands ≤ 1.5 mm above
  the ring (the lens protrudes 13.3 mm from the camera front — measured from the official STEP).
- Fuzzy skin 0.3/0.4 only on side walls — **never** on mating faces (eats ~0.3 mm/side of
  tolerance) and never on the 1.5 mm RF radome (undefined wall in the RF path).
- Logo debossed 0.5 mm (raised text = snag + elephant-foot mush).

## 2 · Orientation — the one that saves the sender

- **body**: opening up, upright — cavity, bosses and ledges all print support-free; horizontal
  wall holes as teardrops.
- **cover / battery door**: outer face on the plate.
- **bottom_shell — THE critical part**: printed **lying on its rear face so the GoPro fingers
  lie FLAT** → layers run along the finger length and opening-shock bending loads the strong
  in-plane direction, not the 18 MPa interlayer bond. Ignore this and **the fingers shear along
  the layers and the sender leaves the helmet at altitude** — the #1 killer in the register.
  Plus: R 1.5 fillet at every finger root, finger zone 100 % infill, M5 steel screw carries the
  clamp (never plastic edges), seam never placed on a finger.

## 3 · Tolerances that actually print (0.4 mm nozzle, calibrated)

| joint | value | why |
|---|---|---|
| press fit (one-time joints only) | 0.0–0.1 mm | PETG creeps — never press-fit anything you reopen |
| sliding fit (door guide) | 0.3 mm | |
| never-jams (cable windows) | 0.5 mm | |
| printed holes | **+0.2 vertical axis · +0.3 horizontal axis + teardrop** | FDM holes print 0.1–0.5 mm undersize |
| switch hole M12×0.75 | **Ø 12.3 through-hole + the switch's own nut** — printed fine threads are a lie (0.46 mm thread depth ≈ one extrusion) | |
| M3 heat-set (Ruthex class) | hole Ø 4.0 × 7.0 deep, boss Ø 9, 0.5 chamfer, ≥ 3 perimeters | manufacturer install spec + insert-study practice |
| lid fit | **inner lip ON THE COVER** (2 × 4 mm, 0.2 clearance/side) — a groove in the body wall would halve the sacrosanct 3.0 mm | |
| wall slicing | **6 perimeters × 0.5 mm = exactly 3.0** — no gap-fill sliver inside the wall | |
| shrink | ASA **+0.8 % isotropic** in the export script (never additionally in the slicer); PETG starts at 1.000 and is calibrated by a 100 mm coupon | |
| stack-up gate | for every joint: nominal gap − (shrink bias + 2×0.15 spread + hole undersize) ≥ 0 — scripted check | |

## 4 · Robustness & environment

- **Material: ASA for the final part** (Tg ≈ 100 °C, UV-stable — a helmet spends whole seasons
  in the sun and 60 °C cars; PETG's HDT ~68–75 °C is too close). PETG for fit prototypes.
  Never PLA. ASA warps: enclosure, brim 6 mm, draft shield, ~105 °C bed.
- No screw ever threads directly into printed plastic (inserts or nuts only).
- Condensation philosophy: **drainage instead of sealing** — Ø 1.5–2 mm weep holes at the
  lowest point of both floors and of the patch cavity (never through the radome).
- The 1.5 mm radome prints as **3 solid perimeters** — no infill sandwich in the RF path.
- Everything inside is form-locked or foam-preloaded — nothing may rattle at 200 km/h.
- Usability at the exit: thumb well Ø 26 around the flush latching button (glove-operable,
  no snag), captive battery door with a ≥ 12 mm thumb tab, light pipe for the VTX status LED
  (position read from the official STEP, not guessed).

## 5 · Coupons before the full case (print these first)

Insert-boss field + pull-out test · switch-panel hole ladder Ø 12.1/12.3/12.5 · door-fit ladder
0.2–0.5 · **GoPro finger pair in the chosen orientation + break test against an upright-printed
control** · bulkhead hole + counterbore + nut test · 100 mm shrink ruler XYZ per material ·
bezel + lens bore against the camera · 1.5 mm radome plate (thickness + opacity check).
Print order: coupons → bottom_shell (riskiest) → body → cover/door. Doors and bottom shells
are wear parts: print two.

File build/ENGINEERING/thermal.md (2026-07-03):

# Thermal design — passive cooling & vent optimum

*Condensed English edition of the project's German derivation (`THERMAL_VENT_OPTIMUM`,
2026-07-02). Labels: **[SOURCE]** = manufacturer/datasheet with URL in the original ·
**[CALC]** = our own engineering calculation, formulas and assumptions disclosed —
**calculated, NOT measured**. Every [CALC] number stands or falls with the measurement
plan in [`../MEASURE.md`](../MEASURE.md).*

Binding constraints: purely **passive** (no fan, no extra electronics — 4 parts, solder-free),
**3.0 mm wall sacrosanct** (vents are cutouts, never thinned wall), upright two-storey layout
(floor 1 = battery, floor 2 = VTX + camera), omni captured in the side wall.

## 1 · The honest headline numbers

- At 1 W RF the Freestyle V2 draws ~14 W → **~13 W becomes heat** (design value; worst 14 W).
  [SOURCE: manufacturer docs + independent review — "~14 W at 1 W/R1", "consumes up to 15 W"]
- **No passive vent design on earth holds 1 W on the ground in still air.** Chimney draft
  delivers tenths of a pascal; ram-air delivers hundreds — a factor of ~10 000. HDZero itself
  says: on the bench, use a fan or low power. [SOURCE + CALC]
- Therefore the design is **two-regime**: (a) chimney vents that make 25 mW continuous and
  200 mW 10-minute-safe on the ground, and (b) the same vents as a flow-through path in
  freefall, where ~500 mm² of slots delivers **4–8× the need**. [CALC]

## 2 · Load cases [all CALC]

| case | mechanism | result |
|---|---|---|
| Ground, still air, 25–35 °C | chimney draft (Δp ≈ 0.06 Pa) + shell convection/radiation | ~4.5–6.5 W removable → **25 mW: holds · 200 mW: ≤ 10 min (≤ 5 min at 35 °C) · 1 W: impossible steady-state** |
| Climb (last ≤ 10 min powered) | same as ground, cooler air | fine at 25 mW; set 1 W only at door-open |
| **Freefall 55–75 m/s** | ram-air through-flow, ΔCp ≈ 0.3 conservative → ~9 L/s through 500 mm² | **≈ 46 W capacity vs 14 W worst need** — even with 50 % blockage 2–4× surplus. The fall is the heatsink |
| Canopy 10–15 m/s | same path, weaker | ~12 W at ΔT 5 K — 1 W holds with reserve |
| **After landing** | hot start + still air + 1 W | protective RF cut in ~1–2 min → **doctrine: OFF within 60 s** |

The VTX's own protection is a **hard RF shutdown** until repowered [SOURCE] — for a live
stream that's a mission kill, so the doctrine limits are *broadcast-guarantee* limits.

## 3 · Architecture (zones, not final coordinates)

```
   OUTLET →  slot band under the lid lip (sides + rear; front is the camera's)
             ┌──────────────────────┐
             │ floor 2: VTX+camera  │  ← 13 W source · thermal pad → wall OPPOSITE the omni
             ├── divider tray ──────┤  ← free openings ≥ 750 mm² (riser channel)
             │ floor 1: battery     │  ← battery sits in the COOL intake stream
   INTAKE →  └──────────────────────┘  ← lowest wall band, sides + rear (floor stays free: mount)
```

- **Chimney through the battery floor: yes.** Intake at the bottom raises the stack height
  (+30–65 % draft), the battery sits in fresh intake air (heat rises away from it), and the
  bottom slots double as condensation drainage.
- **Three facades**: poses change the airflow direction in freefall — vents on sides + rear
  guarantee a windward/leeward pair in every pose, with no moving parts.

## 4 · Slot geometry (one shape solves print, snag and rain)

**Vertical louver slots, 2.5 × 14 mm, tilted 45° downward-outward through the 3.0 mm wall.**

- 2.5 mm: no line-snag catch (flush, no undercut), finger/foreign-body safe, prints without support.
- Vertical + 45° louver: no bridging, self-supporting overhang, and no straight water path in
  (drops can't travel upward). The wall stays 3.0 mm everywhere — a slot is a cutout, not a thin spot.
- Areas: intake ≥ 500 mm² (~15 slots), outlet ≥ 600 mm² (~18 slots, ≈ 1.2× intake — outlet air is
  warmer/bulkier and must never throttle the ram path), divider net free area ≥ 750 mm².
- **A NACA duct was evaluated and rejected** [CALC]: plain slots already give ≥ 4× freefall
  surplus; a NACA inlet would only add margin nobody needs and costs snag safety, printability
  and water-tightness.

## 5 · The thermal pad — honest about what it does

1.5 mm silicone pad, ≥ 3 W/mK, full VTX face (29.2 × 30 mm) to the side wall opposite the omni.
Honest series-resistance math [CALC]: the PETG wall is the bottleneck — on the ground the pad
moves only **~0.6 W of 13 W**. It is still mandatory, because it (1) roughly **doubles the
effective heat capacity** in the power-up window (buys 1–2 min before cut-out), (2) carries
~2.5 W in freefall as a second path, (3) is a set project rule.

**Material:** the pad contact zone can exceed 70 °C in a fault → **ASA preferred for the final
part** (Tg ≈ 100 °C vs PETG ≈ 70–80 °C); PETG is fine for fit prototypes; **never PLA**.

## 6 · Operating doctrine (the design's fifth component)

25 mW on the ground (unlimited) · 200 mW ≤ 10 min · **1 W only at door-open/exit call**
(~2 min before exit: the VTX starts the jump 30–40 K below the cut-out zone and ram-air takes
over at exit) · **OFF ≤ 60 s after landing** · at a 35 °C DZ keep it in the shade / print bright.

*Nothing in this document is measured. The architecture decisions (chimney bottom→top, louver
slots, three facades, no NACA) are robust for any heat load between 5 and 15 W; the numeric
margins await the multimeter + thermometer protocol in [`../MEASURE.md`](../MEASURE.md).*

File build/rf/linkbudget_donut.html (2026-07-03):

# SkyLive · Donut HUD

5.8 GHz link-budget MODEL — not a measured test. Drag the ground station.

TX ANTENNA ORIENTATION

UP/DOWN donut HORIZONTAL donut

Same +2.2 dBic peak, same power — the toggle only re-aims it. UP/DOWN puts the peak toward the ground below; HORIZONTAL puts its NULL straight down.

BODY POSE (sets shadow)

Head-down Belly-earth Sit / head-up Back-fly

Altitude 4000 m

Horizontal drift 500 m

TX peak gain 2.2 dBic

RX patch gain 10 dBic

Side-mount offset relief on

+8.8

dB MARGIN vs −90 dBm

PICTURE ✓

UP/DOWN advantage over HORIZONTAL here

+17.9 dB

Better aiming, not more power. Fixed peak; only the pointing changes.

Model: Friis FSPL + half-wave-dipole toroid (null floored −18 dB) + literature body-shadow (torso −10…−18, head −6…−12 dB) + side-offset relief. −90 dBm lock threshold (HDZero degrades gracefully below). See RF_ANALYSIS_DONUT.md. Verify with NanoVNA SWR + a real jump before trusting.

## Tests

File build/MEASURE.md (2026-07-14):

# SkyLive — What YOU must measure (nothing is guessed)

*Condensed English edition of the project's German measurement protocol
(`MESSPROTOKOLL_SENDER`, 2026-07-03). The project rule: **no dimension is ever estimated.**
Every number is calipered, confirmed against the real part, or taken from a datasheet with the
source noted. Open values stay open until measured — they are never silently filled in.*

If you rebuild this project, the same discipline applies to you: your parts (pigtail batch,
switch clone, patch revision) may differ from ours. The CAD (`cad/spec.py`) marks every
unsourceable dimension as `MEASURE_ME` with a documented fallback — measure, replace, rebuild.

## A · Blocks the final print file (10 minutes with a caliper)

| # | dimension | how to measure | CAD fallback (documented, not trusted) |
|---|---|---|---|
| A1 | **Switch: total depth behind the panel plane** (barrel + body + lugs + cable exit) | hold it through a hole / over a table edge, panel seat → deepest point | 27.0 mm |
| A2 | **Omni (AXII 2) head/puck length alone** (without cable, cable root → tip) | lay it along the caliper | 22.5 mm |
| A3 | **Omni SMA plug**: length + wrench flat size | — | — |
| A4 | **Flange pigtail jack (U.FL→SMA)**: flange W×H, hole spacing, hole Ø | the sheet-metal end of the pigtail | — |
| A5 | **XT30 MATED** (plug + socket connected): total envelope L×W×H | measure the mated pair | window 14 × 9 mm |
| A6 | **MIPI ribbon width** (the kit cable VTX↔camera) | flat | **published nowhere** — must be measured |
| A7 | **TBS 5G8 patch**: PCB thickness + total height incl. connector | — | 3 / ≤ 15 mm |

## B · Important, not print-blocking

- Does the flange pigtail have a **flat (D-shape) on the thread**? → decides D-hole vs
  tooth-washer anti-rotation in the CAD.
- **VTX status LED position** on the board (which edge, mm from corner) — read from the official
  STEP if possible, for the light-pipe bore.
- **Battery pack recheck** (L×W×H hard, cable length to XT30) against the manufacturer's
  60 × 30 × 23 mm — trust, then verify.
- GoPro-mount finger tip radius + pivot offset from a real mount (mount fine-tuning).

## C · Empirical — after printing / with instruments (in order)

1. **VNA S11 of the omni with its coax in the printed clamp** — mandatory before believing any
   RF number (markers 5.65 / 5.8 / 5.95 GHz, target SWR ≤ 2 in band).
   ⚠ The instrument must actually cover 5.8 GHz — a NanoVNA-H does not.
2. **On-helmet detuning** (VNA S11 with the antenna mounted on the real helmet; the patch version of this test belongs to the legacy study).
3. **Thermal A/B test**: 200 mW on the ground, vents open vs taped shut; log U×I with a
   multimeter per power step (always with an antenna attached!). This is the experiment that
   calibrates the whole thermal model.
4. **1.5 m drop test** of the printed-in divider shelf (coupon) with an 80 g battery dummy — the beam
   calculation is not a test.
5. **Fit coupons BEFORE the full-case print** (insert boss, switch hole, door fit, GoPro
   fingers) — plan in [`ENGINEERING/print.md`](ENGINEERING/print.md).

## What happens with the numbers

A1–A7 flow directly into `cad/spec.py` (the fallbacks there are flagged `MEASURE_ME`) →
one rebuild run regenerates all parts, and the build gates (watertightness, interference ≥ 0.5 mm,
wall ≥ 3.0 mm, dimension asserts) check them automatically. No dimension lives in the model
that isn't measured, confirmed, or sourced.

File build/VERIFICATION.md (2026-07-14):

# Verification & Quality — how we make a printable part *trustworthy*

Most "3D-printable" hardware repos hand you an STL and hope. This one treats the gap between
a CAD model and a part that actually works as the real engineering problem. Here is the honest
principle first, then the method.

> **No CAD check can promise "100 % error-free." A gate is a boolean test on a digital model —
> it is not a physical test.** What a good process delivers instead: it catches each *class* of
> error at its own layer, so the chance of an uncaught defect becomes vanishingly small **and**
> whatever slips through shows up *cheaply* (a 5 g coupon) rather than *expensively* (a ruined
> full print). That is why the full print is the **last** step, never the first.

## Defense in depth — seven layers

**1 · Prevention — errors that never happen.**
A single source of truth (`cad/spec.py`) holds every dimension; each is either measured from an
official manufacturer STEP, sourced from a datasheet (URL in a comment), or explicitly flagged as
"must be calipered." No magic numbers live in the model. Everything is parametric, so changing one
number updates the model *and* its checks consistently — no drift between docs, model and renders.

**2 · Automated geometry gates — every build, fail loud.**
Each build asserts: watertight single solids, pairwise interference ≥ clearance, minimum wall,
internal bay envelope, vent open-areas, antenna-anchor fit, switch-head clearance, connector
feed-throughs. **The load-bearing rule:** a gate checks against the *nominal, as-designed* feature
positions — **never against the post-boolean body**. A gate that "passes" only because the conflict
was carved out of the shell is banned; it would hide exactly the structural defect it should catch.
(We learned this the hard way: an early interference gate silently passed while a switch overlapped
a load-bearing screw boss, because the boss had been cut away to make room. Now the check runs on
the intended geometry.)

**3 · Cross-checks & redundancy.**
Key quantities are measured two independent ways — boolean volume vs. summed volume, exported-STL
bounding box vs. the model's own dimensions — so a silent export or transform error can't hide.
Orthographic drawings and shaded renders get a human eye on every geometry change.

**4 · Independent adversarial verification.**
A second, fresh reviewer with its *own* watertight and collision checker re-derives every pairing
and does not trust the builder's gates. Disagreement is the point.

**5 · The CAD → print bridge — where most real defects are born.**
Before printing we read the **slicer's actual toolpaths**, not the CAD: walls the slicer silently
drops, gap-fill worms, overhangs beyond the support-free limit, seam placement, bridges. Walls are
kept to an integer multiple of the extrusion width so no gap-fill lands inside a wall. A worst-case
tolerance stack-up is computed per joint (shrink bias + spread + hole under-size): does it still fit?
Shrinkage compensation, elephant-foot chamfers and per-part print orientation (so the layer lines
never run along the main load direction) are all fixed here.

**6 · Physical coupons — the only real proof before the full print.**
Small test prints of every critical fit — heat-set boss, switch hole, battery door, camera/GoPro
mount, antenna anchor, divider ledge — are printed and tested with the *actual hardware*. Structural
claims (e.g. "the divider survives a 1.5 m drop") are validated with a coupon drop test, not left as
a beam calculation. The clamped antenna gets a VNA S11 sweep (the instrument must cover 5.8 GHz), because the real
RF risk near a printed wall is detuning, not the (calculated, negligible) ~0.15 dB of dielectric loss.

**7 · Measurement & release discipline.**
The handful of values that can't be sourced are calipered and pinned into `spec.py` before anything
is called "final." Until then it is explicitly a *fit prototype* — and it is labelled as one. A
release checklist (below) must be fully green.

## Release checklist

- [ ] All gates pass, checked against **nominal** geometry (no masking by subtraction)
- [ ] Exported-STL bounding box equals the model's dimensions (cross-check clean)
- [ ] Independent verification with no open blocker
- [ ] Slicer preview clean — no dropped walls, no gap-fill worms, support planned
- [ ] Worst-case tolerance stack-up > 0 at every joint
- [ ] Every critical fit passed as a physical coupon (incl. drop test + NanoVNA)
- [ ] All "must-caliper" values measured and pinned into `spec.py`
- [ ] Material is ASA (final) / PETG (prototype), never PLA
- [ ] Honestly labelled: the first print is a fit prototype

*As long as one box is open, it is a prototype — and it is called one.*

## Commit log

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2026-06-06 Repo overhaul: cinematic English README + lens-forward renders + two-generation story
    - New hero/social-preview composite (lens facing the viewer, dark telemetry-HUD look)
    - Both prototypes rendered lens-forward: Gen 1 MK2 (foundation) + Gen 2 v5 (dual antenna)
    - 'Two generations. One idea.' showcase replaces the confusing two-shells comparison
    - Clean lens-forward internals; readable ground-station head; pruned stale/low-quality renders
    - Full English rewrite, demo-first narrative, informational badges, CC-BY-4.0 LICENSE + RF disclaimer
    - Fix factual error: CAD stack is build123d/Python (not OpenSCAD)
    - Refresh pitch decks with the flagship MK2 + dual-antenna pitches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
2026-06-06 Smooth lens-forward turntable, 'dot → live' marquee illustration, remove 200 km/h, non-skydiver clarity
    - New animation: buttery 25fps ping-pong turntable (lens always forward, solid dark bg) replaces the laggy, back-facing assembly.gif
    - New marquee illustration 'dot_to_live.svg' (self-animating): what the ground sees (a dot) vs what SkyDive·Live shows (the freefall POV, same moment) — the whole thesis in one glance, gets non-skydivers instantly. In README top + a new Pages 'idea in one glance' band
    - Removed '200 km/h' everywhere (README, hero/og image, live site chip + windtag, both decks) — freefliers go faster; speed claim dropped
    - Accessibility: glossed 'head-down (falling head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
2026-06-06 Fix 3D for real: vendor model-viewer locally + poster fallback (no CDN dependency)
    Root cause of the empty 3D box: the unpkg CDN module wasn't loading in the user's browser.
    - Vendored model-viewer.min.js into docs/vendor/ and reference it locally (no external CDN)
    - Added an <img slot="poster"> fallback inside <model-viewer> so the device image shows even if the module never loads
    - Verified: local HTTP server with ALL external traffic blocked → defined:true, loaded:true, visible:true, 0 external requests, model renders
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2026-06-06 CAD package for SolidWorks: STEP + STL + 3MF for both builds (MK2 + v5), exact current constellation
    - New cad/ folder: v5_dual_antenna (7 parts) + mk2_foundation (3 parts), each as individual STEP (AP242 solids) + a pre-positioned ASSEMBLY.step, plus STL + 3MF. All watertight, generated from the parametric build123d sources.
    - cad/README.md: SolidWorks opens STEP natively as editable solids (native .SLDPRT can only be written by SolidWorks itself)
    - Fixed print_parts + README + BUILD antenna labels: the antenna shell is the −X SIDE end-cap (flush RF window, patch, alu ground-plane), and the antenna module SCREWS on (4× M3) — not 'bottom/clipped' (thanks to the skeptical second look)
    C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
    [antenna_module_top.3mf, antenna_module_top.step, antenna_module_top.stl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]
2026-06-06 Universal deck distribution: host all decks on Pages + tap-to-open hub + PDFs + v5 English
    - Problem: HTML decks are hard for people to open; no offline file does interactive animation on every device. Solution: a LINK (Pages) for full animation/interactivity on any device + a PDF fallback for offline/email.
    - New v5 ENGLISH deck (dual_antenna_EN) — translated, 200 km/h removed, jargon glossed, 0 console errors
    - Hosted all 4 decks on Pages (docs/decks/) + a tap-to-open hub (docs/decks/index.html): 'works on any phone or computer, nothing to install'
    - PDF of every deck (offline/email fallback): pitch_EN/DE (35p), dual_antenna_EN/DE (8p)
    - README + site: all 'Pitch deck' links now point at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
2026-06-06 Decks: remove the 4 graphic slides (27-30) from the full-system pitch (EN + DE)
    - They added little new info; removed from pitch_EN + pitch_DE (35 → 31 slides), repo + hosted copies
    - The graphics are preserved as renders/{dot_to_live.svg,gopro_size.png,signal_flow.svg,print_parts.svg} and still live in the README + the web site (the two-skydivers 'dot → live' animation included)
    - Regenerated pitch_EN/DE PDFs to 31 pages
    - Verified: both decks load, 31 slides, 0 console/page errors, clean flow (loop → roadmap → close), no blank slides
2026-06-06 v5 deck slide 4: real orbitable 3D of the components (drops the housing-disappear) + correct antenna copy
    - Replaced the two-PNG ghost/solid crossfade with a self-contained <model-viewer> of the colored v5 components (exploded, identity colors), freely orbitable in all directions; inline model-viewer + base64 GLB so it works via the link AND as a file (verified file:// + http, 0 errors)
    - Fixed the physics: 'One looks down' → 'One to the side. One up.' (the patch sits in the −X side end-cap, the dipole on top) — EN + DE
    - Regenerated v5 PDFs
2026-06-06 Rethink the GoPro size comparison: true-to-scale, same orthographic view
    The old one mixed a 3/4 render (sender) with a flat outline (GoPro) → invalid comparison. New gopro_compare.svg shows both as front-orthographic silhouettes at the same scale: same height (51 mm), sender a little narrower (57 vs ~71 mm), with a scale-honest dimension. Replaces the old gopro_size.png in README + site.
2026-06-06 BOM: correct TBS 5G8 patch gain (~8→~5 dBi) and tinySA (Ultra→Ultra+ ZS-406)
    Two factual fixes from the latest sourcing verification:
    - TBS 5G8 RHCP is ~5 dBi/110°, not ~8 dBi (ENGINEERING.md already used the correct 5 dBi — BOM now consistent).
    - The older tinySA Ultra tops out ~5.4 GHz, below the 5.8 GHz band, so it cannot measure the link; the Ultra+ (ZS-406, to 6 GHz) is required.
    Note: the '8 dBi' in the pitch decks is the RX ground-patch in the link-budget equation (a different antenna) and is intentionally left as-is.
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2026-06-07 Wire 4-way belly star POV into the live-stream demo feed
    The 'A body is a shadow' demo stream box was empty. Add a hand-built 4-way
    belly-formation POV (pov_feed.svg: 3 teammates in the round + the viewer's
    own arms gripping in, cyan grip-glow) as the .feed image, layered over the
    sky->earth gradient. Existing .lost state now glitches/desaturates it on
    antenna block -> makes 'never lose the image' playable. Showcase + both decks.
2026-06-07 v5 consistency: landing 'Engineered' is passive thermal, not self-thinking fan
    v5 is passive — the active self-thinking fan belongs to Gen1 MK2 (correctly
    attributed in README + two_generations render). The landing page's
    'Engineered, not hoped' section wrongly sold 'cooling that thinks for itself'
    as a current feature. Reframe to passive thermal + redraw cooling.svg
    (no fan/no moving parts, ram-air carries the heat, delta-T 6 K). Also remove
    the now-orphan docs/3dtest.html diagnostic page (was live on Pages) and
    docs/splitscreen.svg.
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2026-06-08 Honest link budget: real ENGINEERING.md numbers + signal tracks the fall
    Replace the untraceable '+9 dB / +10 dB / 11.6 km' with the actual figures
    from ENGINEERING.md: +30 dBm TX, +18 dB antenna gain (TX +5 / RX +13),
    -119.8 dB FSPL, -5 dB cable+polarisation, -90 dBm threshold -> +13.2 dB belly
    margin; head-down -13.8 dB recovered to +2.0 dB by the dual antenna. Fixes the
    animation bug Tom spotted: the jumper now actually descends and the
    signal-strength bar grows in lockstep (same 5s ease-in) -> stronger as he
    falls, instead of strengthening before he moves. Updated landing card, stat
    tile, both SVG copies (docs + renders), README table + alt text.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
2026-06-08 README (the page everyone lands on): purge the abandoned self-thinking cooling, sync v5 assets
    The README is the real front door (github.com/SchoenTom/skydive-live); the
    Pages site is secondary. Fix it there, not just on the website:
    - Remove the prominent 'Self-thinking cooling' paragraph + fan chart from the
    Gen 1 section (the active fan is abandoned; v5 is passive).
    - two_generations.png: replace the Gen 1 label 'Active, self-thinking cooling'
    with 'Single antenna · belly link' — honest, and it sets up Gen 2's dual antenna.
    - Sync the realistic GoPro (renders/gopro_compare.svg) that was only on the website.
    Root cause of the drift: I'd been editing docs/ (website) copies but not th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
2026-06-09 BOM in English + drop duplicate asset dirs (decks/, models/)
    ENGLISH README linked a German BOM — the language break is gone.
    decks/ and models/ duplicated docs/ byte-for-byte (the double
    maintenance that caused the last numbers drift); docs/ is the single
    source, GLBs and decks ship with the v1.0 release (EN deck uploaded).
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2026-06-09 Purge the last Class-E claims + publish the worked link-budget chains
    The hero chip, README stack line and both pitch decks' comparison/spec
    rows still sold Class-E as the legal basis — replaced with the actual
    plan of record (PMSE/SRD) and a dual-antenna chip. ENGINEERING.md gains
    Appendix A: every scenario's dB chain written out line by line with the
    pattern assumptions, so the math is publicly checkable — including the
    sanity check that reproduces the retired +13.2 figure.
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2026-06-10 Full-repo audit pass: kill the last stale claims, dead anchor, orphans
    Three audits (markdown, landing page, decks) + verification found:
    - pitch decks still carried the retired 2.5 W dissipation math (energy
    balance says 13-14 W — the appendix now shows ground-idle as the
    danger case, cutoff doctrine, freefall dT~6K), a bottom-patch
    description ('beams downward') for what is now a side patch, and one
    'Klasse&nbsp;E' that a non-breaking space hid from every earlier grep
    - README GIF linked to a #play anchor that never existed (now #antenna)
    - relative release/issue links made absolute (break off-github)
    - 'proven/proof' wording for never-printed hardware softened; thermals
    headin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
2026-07-03 Pages site: rework to the one-socket/two-antennas doctrine
    Signature demo now teaches down-patch vs donut-omni coverage (one at a
    time, manual swap, ground diversity as third actor) — no dipole, no
    electronic switch. Link-budget and thermal SVGs retexted to the honest
    2026-07 numbers (donut aiming, body shadow, 13 W doctrine). TBD-CAD-M6
    markers where the new model/renders/decks land.
2026-07-03 Purge the superseded design from the tree
    Deletes on sight per the rebuild vision: MK2/v5 CAD geometry (top
    antenna module, dipole, RF switch), the two-generations render set, the
    dual-antenna deck suite, the stale printed-parts/size-compare figures,
    and the root BOM/BUILD/ENGINEERING (replaced by the build/ tree).
    docs/ GLBs+posters stay so the live page keeps working until the new
    model lands (TBD-CAD-M6).
    [antenna_module_top.3mf, antenna_module_top.step, antenna_module_top.stl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]
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2026-07-03 CITATION + DISCLAIMER: retitle off the dual-antenna framing, honest safety list
    antenna-diversity keyword -> antenna-swap; abstract describes the
    one-socket/two-antennas sender + ground diversity; disclaimer drops the
    unbuilt over-temperature cutoff and names the real gates (SAR, AAD,
    thermal doctrine), links build/LEGAL_DE.md.
2026-07-03 Fill CAD-M6 dimension markers: gates pass, 63x71x85/101mm
    Resolve the text TBD-CAD-M6 markers with the verified outer dimensions of
    both antenna variants. Visual-asset markers (renders, GLB swap, posters,
    decks) stay open until the design is signed off and final beauty renders exist.
2026-07-04 Add build/VERIFICATION.md (7-layer QA method); precise radome loss ≈0.15 dB
    Design-independent additions: the verification/anti-error methodology
    (honest: gates != physical test, coupons before full print) and the
    calculated radome transmission loss. No geometry numbers touched.
2026-07-04 BOM: add mandatory battery foam preload (safety-critical)
    The 2 mm foam that stops the pack flying free in the bay was missing from
    the parts list. Design-independent safety item.
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2026-07-05 build(BOM): add §6 Alternatives with verified dimensions
    Add alternative components with published L×W×H / Ø×L and honest
    fit notes across 7 categories (VTX, camera, battery, antenna, switch,
    inserts, Wago). Each alt marked fits-as-is vs fits-with-rework;
    unpublished dims flagged rather than guessed. Sources linked.
2026-07-05 docs(pages): rebuild site on the five-act "staun" dramaturgy
    Restructure the GitHub Pages site (docs/index.html) to the approved
    REPO_GENIAL_KONZEPT narrative — show above, build below:
    1. The moment — full-viewport hero, single claim
    "Live from 4 km above the drop zone — 14 ms behind reality." + one CTA
    (assets/hero.png with animated-sky fallback if the render is absent).
    2. The reveal — assets/exploded.png slot (clean fallback) +
    "No flight controller. No BEC. No solder on the sender. Four parts."
    3. Interactive — model-viewer swapped to models/anton20_assembled.glb /
    models/anton20_exploded.glb, existing poster PNGs as fallback.
    4. The physics — five nugget card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
2026-07-05 Antenna strain relief: adopt the real T-slot principle (both short sides) + simplified battery door
    - 2.9 mm press-fit slot from the top edge, round seat, flat T-piece cover,
    2x vertical M2x8 (heads up) — cable exits upward, omni stands above the case;
    notched + blind T-piece variants, sides freely swappable
    - battery door: interior screw boss removed (would have collided up to 2 mm
    with the 61 mm swollen pack — new [akku-frei] gate proves the bay empty),
    replaced by a flat top tab + 1 M2 into wall+shelf ledge; grip dimple dropped
    - WHAT_THE_GATES_CAUGHT: new chapter on the door-boss save
    [skylive_V3_min_battery_door.stl, skylive_V3_min_ze_tee_blind.stl, skylive_V3_min_ze_tee_kabel.stl]
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2026-07-06 Final sender state: measured battery + M2 door insert, vented door, 3.0 mm GoPro teeth, camera-side bay slit; fresh hero/exploded renders + GLBs; assembly guide step renders + honest photo notes repl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
    [skylive_V3_min_battery_door.stl]
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2026-07-06 Antenna doctrine, stated correctly: the omni hangs rotated 90 deg with its bell at the case edge, axis across the body — the donut fires down/up instead of aiming a null at the receiver in head-up/he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
2026-07-06 Fly-in corrected to the antenna doctrine: omni bell at the case edge, axis across the body — GLB animation + README loop re-rendered
2026-07-06 Antenna doctrine, finally right: coax runs horizontally through the wall
    The fly-in model had the coax rising out of the roof — wrong. Per the
    reference build photo: the semi-rigid passes horizontally through the
    round seat in the short wall, the T-piece drops onto it like a clamp
    nose, and the bell sits directly against the wall, axis pointing
    through it. Donut fires down/up/all around.
    - components GLB + flyin850.glb + flyin.gif + QUICKSTART still rebuilt
    - README, ASSEMBLY_STEPS, rf/README, landing nuggets + demo label fixed
    - superseded 'sealed capsule' nugget replaced by the 90-degree-turn story
2026-07-06 Optional cable-side T-piece (06) + horizontal-cable doctrine in all build docs
    The blind T-pieces Tom prints stay untouched (both bodies byte-identical,
    all gates green). New: build_aze_tee(notch=True) now cuts the correct
    U-notch — Ø3.2 horizontal at seat height, open toward the stem's bottom
    edge so the T drops over the lying cable — replacing the old flange notch
    that had the cable rising upward. Shipped as skylive_V3_min_ze_tee_cable.stl.
    A new gate lays a nominal Ø3.1 coax in the seat and asserts zero contact
    with the mounted T; its first run caught a 0.05 mm flange graze (0.025 mm³),
    fixed by running the relief through the flange. Documented in
    WHAT_THE_GATES_CAUGHT. PRINT_DE/Q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
    [skylive_V3_min_ze_tee_cable.stl]
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2026-07-06 Pages via Actions workflow — retire the hanging legacy builder
    The legacy Jekyll builder hung for 2h and errored twice today on
    commits that never touched docs/. This deploys docs/ as a static
    artifact: deterministic, logged, no Jekyll.
2026-07-06 Lid fix: 3.4 counterbore went clean through the 3.0 lid — heads now seat on a 0.4 spotface
    Tom's catch at the printed part: the M3 counterbores (Ø6.1×3.4, per the
    head+0.4 convention) were deeper than the 3.0 mm lid itself — the cap
    head would have dropped straight through and clamped nothing. Deeper
    sinking is impossible anyway: the corner screws sit over the 1.5 mm
    rebate flange. The lid now uses a 0.4 spotface; heads stand 2.6 proud
    (same family as the T-piece M2 heads). New [deckel-kopf] gate asserts
    real bearing material under every head on both senders. All viewer GLBs
    regenerated; STEP now exports alongside every STL so the two can't drift.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
    [skylive_V3_min_cover_floor2.stl, skylive_mini300_cover_floor2.stl]
2026-07-06 T-clamp 2.0 + reference-build lid counterbore — the mechanism, corrected end to end
    A neutral review of the reference build's STEP files overturned the
    press-fit story this repo told: the seat has clearance (Ø3.2 on Ø3.1)
    and the clamping force comes from the two vertical M2 screws pulling
    the T-piece's R1.55 convex nose 0.4 mm onto the cable. Both senders
    rebuilt to that mechanism (mouth → guide slot → round seat → nose stem),
    no drilling or notching anywhere, and the old 'never touch the cable'
    gate replaced by its inverse — a clamp gate asserting the defined
    1.15 mm³ nose engagement on every rebuild.
    The roof lid likewise now carries the reference lid's real counterbore
    (Ø6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
    [skylive_V3_min_cover_floor2.stl, skylive_V3_min_ze_tee.stl, skylive_mini300_ze_tee.stl]
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2026-07-14 Review-driven hardening + the 2026 pitch: gate v2 (cusp vs. membrane), three real fixes, mid-size joins the family
    - printability gate v2: classifies thin zones (surface+plateau = FAIL, cusp/blade = WARN),
    calibrated on a synthetic membrane, an acute wedge, the printed body and the louvers;
    ships in build/cad and runs as a hard export gate in all three model scripts
    - three real bugs it caught, all fixed: flush-tee counterbore floor 0.5 -> 1.0 mm,
    XT30 clamp bar 0.7 -> 1.7 mm floor over the cable grooves (all sizes),
    mid-size groove positions rescaled to the narrower wall
    - battery-door swing noses get a 45-degree root wedge (the reviewer's 'radii there too'),
    door tab apron story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
    [skylive_V3_min_battery_door.stl, skylive_V3_min_cover_floor2.stl, skylive_V3_min_xt30_latch.stl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]
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2026-07-14 The pitch speaks English now — and it's hers
    - exact English twin of the 2026 deck (all slides, SVG labels, JS phase texts,
    link-budget verdicts; airstream in mph where it reads natural)
    - the jumper is a she throughout both languages: the ground sees the jump
    through HER eyes
    - careful de-marketing pass: tightened the wordiest bodies (vision, VTX, camera,
    battery, cooling) — facts kept, filler cut, spec lists untouched
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2026-07-22 XT30 latch v2: hat profile - the screw holes finally close, and the part stops hiding in the brim
    Builder finding at the printer (2026-07-22): the latch printed almost as flat
    as its brim (3.0 mm), and the two M2 bores were open notches at the ends.
    Root cause in the CAD: hole centres sit at +/-4.0 from the saddle centre
    (fixed by the cores in the body), but the bar is only 7.9 long - half-length
    3.95, so the bores broke through both end faces since v1.
    v2 keeps the housing untouched and fixes the part around the constraint:
    - foot = exactly the old footprint (slide fit in the saddle, both
    counter-grooves unchanged) up to 1.7 above the saddle top
    - above that a longer hat (12.2) fully enc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
    [skylive_V3_min_xt30_latch.stl, skylive_mid_xt30_latch.stl, skylive_mini300_xt30_latch.stl]
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2026-07-25 Round 2 goes public: 71mm mid STLs, layer lab, red-pen story
    - fresh mid STLs from the round-2 build (F0-F5 + F3b door fans), 6/6 printability
    - viewer: mid tab at 71 x 38 x 48 with new hotspots (switch bay, camera foot, straight teeth)
    - compare.glb rebuilt from current STLs (old scene still carried the 69mm body)
    - poster_mid re-rendered from the new GLB (white studio, matches the set)
    - index: new interactive 'layer lab' — print a tooth two ways, lever it, watch the
    90-degree hook snap at the seam while the rooted 45-degree fan holds; six fix cards
    with their gate/diff proofs
    - README + build guides: dims updated, round-2 paragraph with the one-material doctrine
    - .gitignore: local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
    [skylive_mid_battery_door.stl, skylive_mid_body.stl, skylive_mid_cover_floor2.stl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]
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2026-07-26 F3c: tooth root collar hugs the flap's R7.1 rounding
    The tongue's edge rounding recedes across the full tooth band (straight edge
    only |y|<2.1) - the F3b fans left a visible re-entrant groove where the curve
    pulled away from the tooth ('die Abrundung loest sich davon ab'). One full-width
    root collar per tooth now replaces the two 45-degree fan prisms: flap underside
    to 6mm into the plate bulk, across the old fan envelope (root width 8.6).
    Gates unchanged: door-in-body 0.000mm3, swing 2deg=0.08/4deg=0.13, 6/6
    printability; mesh_diff confined to the root tip zones, 0 stray points.
    [skylive_mid_battery_door.stl]
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2026-07-26 One principle, three senders: round-2/3 fixes ported to 850 and Mini 300
    - camera foot on the shelf, wall-to-wall XT30 clamp bridge + flat latch v3,
    straight door teeth with full-width root bar, omni side-holders removed,
    inverted cap gates - transplanted from the mid, re-proven by each model's gates
    - 850 lid: 2 diagonal M3 (was 3); Mini keeps its 2 edge screws - the diagonal
    port FAILED its gate honestly (corner boss inside VTX envelope, 320mm3)
    - lid rim audit: mid Y-lap 2.0->1.25 (standing lip was 0.68mm, under the 1mm
    rule; now 1.43) - 850/Mini measured at 1.43-1.45, no change needed
    - vent-through gate (19/19 free 45deg paths per door louver) now in all builds
    - all print files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
    [skylive_V3_min_battery_door.stl, skylive_V3_min_body.stl, skylive_V3_min_cover_floor2.stl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]
2026-07-27 Fit-print verdict: the mid grows +1mm on every axis - 72 x 39 x 49
    The real wrapped Tattu 300 bound in the 18.25mm guide light. Growth lands where
    the pack lives: guide light 18.75/16.55, door opening 19.5x16.5, bay +1 in all
    three axes. Side effects, all measured: switch bay 13.8->14.8mm (full-body gate
    0.000), lid lip 1.43->1.95, swing gates looser (0.06/0.10), tees stay identical
    across models. Guide-window gates updated to the fit-print spec. All gates
    green, 6/6 printability, vents 19/19; print files, STEPs, GLBs, poster, docs.
    [skylive_mid_battery_door.stl, skylive_mid_body.stl, skylive_mid_cover_floor2.stl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]
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2026-07-27 Lid seat back to a full 2.0mm on Y - the growth paid for it
    The 07-26 lip fix had traded seat width (2.0->1.25) for outer lip; with the
    +1mm Y growth both fit: seat uniform 2.0 all around, standing lip measured
    1.20mm (still above the 1mm rule). Cover flange follows parametrically.
    [skylive_mid_body.stl, skylive_mid_cover_floor2.stl]
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2026-07-27 Lens window 13.0mm - snug by request, file-to-fit
    Barrel measures 12.89-12.90; the owner wants 0.05 per side and will file it
    open if it binds. Volume delta +31.2mm3 vs +31.2 theoretical. All three
    senders, bodies redeployed with 0 open edges.
    [skylive_V3_min_body.stl, skylive_mid_body.stl, skylive_mini300_body.stl]
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
